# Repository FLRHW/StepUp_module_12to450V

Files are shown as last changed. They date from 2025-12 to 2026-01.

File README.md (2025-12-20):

<p align="center" width="100%">
  <a href="https://github.com/FLRHW/StepUp_module_12to450V/actions/workflows/ci.yaml">
    
  </a>
</p>

<p align="center" width="100%">
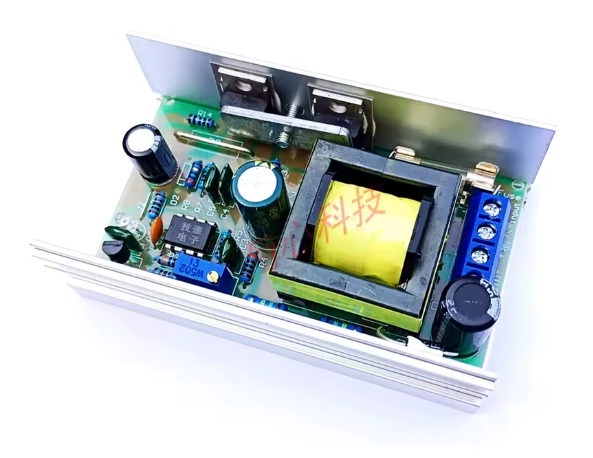
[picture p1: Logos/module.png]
    
</p>

***

<p align="center">
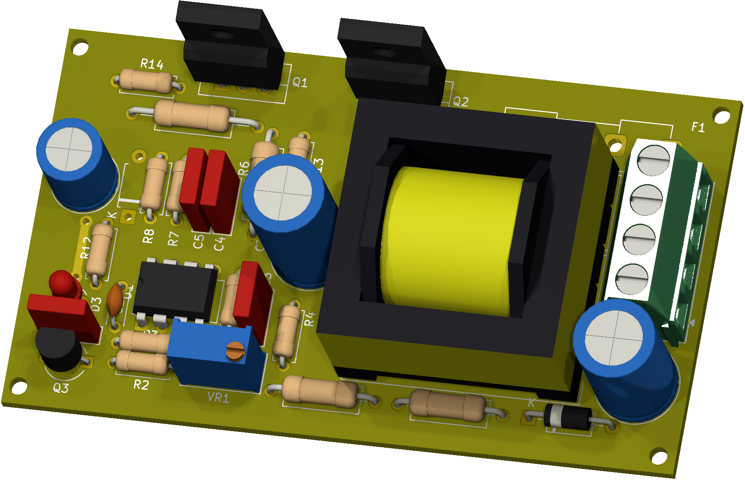
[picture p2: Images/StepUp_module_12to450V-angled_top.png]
3D Top Angled
  
&nbsp; &nbsp; &nbsp; &nbsp;
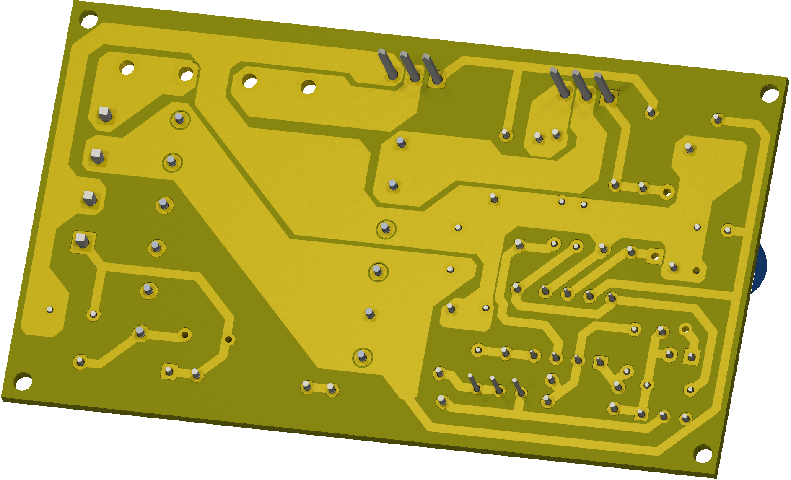
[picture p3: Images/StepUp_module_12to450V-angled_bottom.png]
3D Bottom Angled
  
</p>

***

# **StepUp_module_12to450V**
This repository contains a reverse‑engineered KiCad schematic and PCB layout from a commercial module originally purchased from AliExpress.

## Project overview
This project documents the electrical design and PCB layout of a third‑party module by recreating them from scratch in KiCad for learning, repair, and interoperability purposes. The repository does not include any original vendor design files, firmware, branding, or trademarks.

## Origin and scope
Original hardware: generic module purchased from AliExpress (exact vendor and listing may change over time, the following terms can help finding similar modules: "70W DC-DC 12V 24V To 200V-450V Voltage Adjustable Boost Power Converter Nixie Clock Tube Amplifier Capacitor Charging").  
Status: unofficial, reverse‑engineered reference design; not affiliated with, endorsed by, or supported by the original manufacturer or seller.  
Contents: KiCad schematic, PCB layout, netlists, and supporting documentation created from measurements and inspection of a physical unit.

## Intended use
This repository is intended for:
* Educational use and study of the circuit;
* Repair, modification, or replacement of compatible hardware;
* Integration into hobby or research projects, subject to any third‑party IP that may apply in your jurisdiction. Users are responsible for checking any patent, copyright, or regulatory constraints that may apply to their own use.

## License
The KiCad design files and documentation in this repository are released under the CERN Open Hardware Licence v2 – Permissive (CERN‑OHL‑P‑2.0). SPDX identifier: CERN-OHL-P-2.0 See the LICENSE file for the full legal text and conditions.  
In short and non‑legal terms, you are free to use, modify, manufacture, and distribute hardware based on these files, provided you respect attribution requirements and the terms in the license.

## Trademarks and third‑party rights
All product names, logos, and brands of the original module are the property of their respective owners and are not included or licensed here.  
Any reference to third‑party marks is purely descriptive and does not imply endorsement or affiliation.  
If you are the rights holder for the original hardware and have concerns about this documentation, please open an issue in the repository.

## Safety and disclaimer
* The design is provided as is, with no warranty of any kind;
* Use it at your own risk; always review the schematic, layout, and component ratings before using it;
* High voltage can cause injury, death, or damage to equipment; ensure appropriate protections and testing procedures.

## Contributing
Contributions are welcome. Please use pull requests and issues to propose changes or discuss potential improvements.

***

## DIRECTORY STRUCTURE
    │
    ├─ Computations       # Misc calculations
    ├─ HTML               # HTML files for generated webpage
    ├─ Images             # Pictures and renders
    │
    ├─ kibot_resources    # External resources for KiBot
    │  ├─ colors          # Color theme for KiCad
    │  ├─ fonts           # Fonts used in the project
    │  ├─ scripts         # External scripts used with KiBot
    │  └─ templates       # Templates for KiBot generated reports
    │
    ├─ kibot_yaml         # KiBot YAML config files
    ├─ KiRI               # KiRI (PCB diff viewer) files
    │
    ├─ lib                # KiCad footprint and symbol libraries
    │  ├─ 3d_models       # Component 3D models
    │  ├─ lib_fp          # Footprint libraries
    │  └─ lib_sym         # Symbol libraries
    │
    ├─ Logos              # Logos
    │
    ├─ Manufacturing      # Assembly and fabrication documents
    │  ├─ Assembly        # Assembly documents (BoM, pos, notes)
    │  │
    │  └─ Fabrication     # Fabrication documents (ZIP, notes)
    │     ├─ Drill Tables # CSV drill tables
    │     └─ Gerbers      # Gerbers
    │
    ├─ Report             # Reports for ERC/DRC
    ├─ Schematic          # PDF of schematic
    ├─ Templates          # Title block templates
    ├─ Testing
    │  └─ Testpoints      # Testpoints tables      
    │
    └─ Variants           # Outputs for assembly variants

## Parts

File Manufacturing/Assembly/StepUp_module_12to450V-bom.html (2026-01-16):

 | Bill of Materials
 | Schematic: StepUp_module_12to450V Variant: RELEASED Revision: 1.1.0 Date: 2025-12-20 KiCad Version: 9.0.6+1 | Component Groups: 22 Component Count: 31 (per PCB) Fitted Components: 31 (per PCB) Number of PCBs: 1 Total Components: 31 (for 1 PCBs)
Row | Quantity Per PCB | References | Value | Datasheet | Footprint | Description | Manufacturer | Manufacturer Part Number | Supplier Part Number
1 | 3 | C1 C4 C5 | 10n | ~ | C_Rect_L7.0mm_W2.0mm_P5.00mm | Unpolarized capacitor
2 | 1 | C3 | 3,3n | ~ | C_Rect_L7.0mm_W2.0mm_P5.00mm | Unpolarized capacitor
3 | 1 | C2 | 100n | ~ | C_Disc_D4.3mm_W1.9mm_P5.00mm | Unpolarized capacitor
4 | 1 | C8 | 10u | ~ | C_Radial_D10.0mm_H16.0mm_P5.00mm | Polarized capacitor
5 | 1 | C6 | 100u | ~ | C_Radial_D8.0mm_H11.5mm_P3.50mm | Polarized capacitor
6 | 1 | C7 | 1000u | ~ | C_Radial_D10.0mm_H20.0mm_P5.00mm | Polarized capacitor
7 | 3 | D4 F1 TR1 | ? | ~ | D_A-405_P10.16mm_Horizontal | Diode Fuse
8 | 1 | D3 | LED | ~ | LED_D3.0mm | Light emitting diode
9 | 1 | J1 | Screw_Terminal_01x04 | ~ | TerminalBlock_Phoenix_MKDS-1,5-4_1x04_P5.00mm_Horizontal | Generic screw terminal, single row, 01x04, script generated (kicad-library-utils/schlib/autogen/connector/)
10 | 2 | Q1 Q2 | HY1707 | ~ | TO-220F-3_Vertical | N-MOSFET transistor, gate/drain/source
11 | 1 | Q3 | S8050 | http://www.unisonic.com.tw/datasheet/S8050.pdf | TO-92_Inline_Wide | 0.7A Ic, 20V Vce, Low Voltage High Current NPN Transistor, TO-92
12 | 1 | R9 | 13.7m | ~ | R_Axial_DIN0309_L9.0mm_D3.2mm_P15.24mm_Horizontal | Resistor
13 | 1 | R8 | 20 | ~ | R_Axial_DIN0207_L6.3mm_D2.5mm_P7.62mm_Horizontal | Resistor
14 | 1 | R14 | 100 | ~ | R_Axial_DIN0207_L6.3mm_D2.5mm_P7.62mm_Horizontal | Resistor
15 | 1 | R6 | 150 | ~ | R_Axial_DIN0309_L9.0mm_D3.2mm_P12.70mm_Horizontal | Resistor
16 | 2 | R2 R12 | 1k | ~ | R_Axial_DIN0207_L6.3mm_D2.5mm_P7.62mm_Horizontal | Resistor
17 | 1 | R4 | 3k | ~ | R_Axial_DIN0207_L6.3mm_D2.5mm_P7.62mm_Horizontal | Resistor
18 | 3 | R5 R7 R13 | 5,1k | ~ | R_Axial_DIN0207_L6.3mm_D2.5mm_P7.62mm_Horizontal | Resistor
19 | 1 | R3 | 100k | ~ | R_Axial_DIN0207_L6.3mm_D2.5mm_P7.62mm_Horizontal | Resistor
20 | 2 | R10 R11 | 140k | ~ | R_Axial_DIN0309_L9.0mm_D3.2mm_P12.70mm_Horizontal | Resistor
21 | 1 | U1 | UC3845 |  | DIP-8_W7.62mm
22 | 1 | VR1 | 5k | ~ | Potentiometer_Bourns_3296W_Vertical | Trim-potentiometer
Color reference for columns:
KiCad Fields (default)
Generated Fields
User Fields
Empty Fields

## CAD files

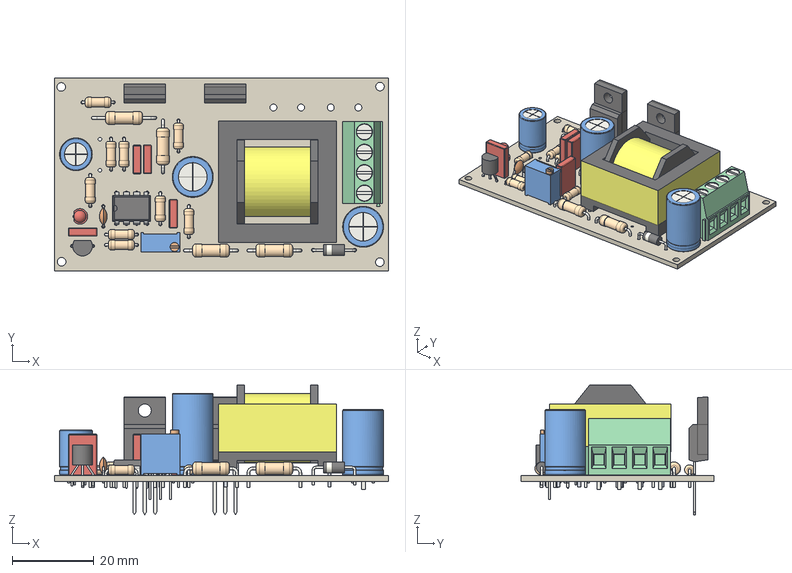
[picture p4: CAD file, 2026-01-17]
3D/StepUp_module_12to450V.step
81.8 x 47.2 x 31.8 mm
C_Rect_L7.0mm_W2.0mm_P5.00mm x 4
R_Axial_DIN0309_L9.0mm_D3.2mm_P12.70mm_Horizontal x 3
LED_D3.0mm
TerminalBlock_Phoenix_MKDS-1,5-4_1x04_P5.00mm_Horizontal
R_Axial_DIN0207_L6.3mm_D2.5mm_P7.62mm_Horizontal x 9
DIP-8_W7.62mm
C_Radial_D10.0mm_H16.0mm_P5.00mm
Trafo_12to450V_module
TO-220F-3_Vertical x 2
R_Axial_DIN0309_L9.0mm_D3.2mm_P15.24mm_Horizontal
C_Disc_D4.3mm_W1.9mm_P5.00mm
TO-92_Inline_Wide
C_Radial_D8.0mm_H11.5mm_P3.50mm
Potentiometer_Bourns_3296W_Vertical
D_A-405_P10.16mm_Horizontal
C_Radial_D10.0mm_H20.0mm_P5.00mm
kibot_6br3e5ev_PCB

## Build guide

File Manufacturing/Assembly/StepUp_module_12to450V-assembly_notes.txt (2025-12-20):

ASSEMBLY NOTES (UNLESS OTHERWISE SPECIFIED)

1)	DO NOT POPULATE PARTS MARKED WITH A RED CROSS.

2)	IF CONFLICTING INFORMATION IS FOUND BETWEEN THE ASSEMBLY
	FILE AND BOM, BOM SHOULD BE USED AS THE MAIN SOURCE.

3)	DOT IDENTIFIES PIN #1 LOCATION AND DEVICE ORIENTATION
	WHEN VIEWED FROM THE TOP.

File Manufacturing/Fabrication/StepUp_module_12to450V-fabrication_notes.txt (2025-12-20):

FABRICATION NOTES (UNLESS OTHERWISE SPECIFIED)

1)	FABRICATE PER IPC-6012A CLASS 2.

2)	OUTLINE DEFINED IN SEPARATE GERBER FILE WITH
	"Edge_Cuts.GBR" SUFFIX.

	DIMENSIONS OF CIRCUMSIZED RECTANGLE SHOWN ON THIS
	DRAWING ARE FOR REFERENCE ONLY.

3)	SEE SEPARATE DRILL FILES WITH ".DRL" SUFFIX 
	FOR HOLE LOCATIONS.

	SELECTED HOLE LOCATIONS SHOWN ON THIS DRAWING 
	ARE FOR REFERENCE ONLY.

4)	SURFACE FINISH: IMMERSION GOLD

5)	SOLDERMASK ON BOTH SIDES OF THE BOARD SHALL 
	BE LPI, COLOR TOP: #8071501A / BOTTOM: GREEN.

6)	SILK SCREEN LEGEND TO BE APPLIED PER LAYER 
	STACKUP USING WHITE NON-CONDUCTIVE EPOXY INK.

7)	ALL VIAS ARE TENTED ON BOTH SIDES UNLESS 
	SOLDERMASK OPENED IN GERBER.

8)	VENDOR SHOULD FOLLOW ROHS COMPLIANT PROCESS 
	AND Pb FREE FOR MANUFACTURING

9)	PCB MATERIAL REQUIREMENTS:

	A.	FLAMMABILITY RATING MUST MEET OR EXCEED 
		UL94V-0 REQUIREMENTS.
	B.	Tg 170 C OR EQUIVALENT.
	C.	EQUIVALENT MATERIAL SHALL BE RoHS COMPLIANT, 
		HALOGEN FREE AND APPROVED BY FR.

10)	DESIGN GEOMETRY MINIMUM FEATURE SIZES:

	BOARD SIZE				81.800 × 47.200 mm
	BOARD THICKNESS		1.660 mm
	TRACE WIDTH			1.000 mm
	TRACE TO TRACE		0.200 mm
	MIN. HOLE (PTH)			0.800 mm
	MIN. HOLE (NPTH)		2.100 mm
	ANNULAR RING			0.320 mm
	COPPER TO HOLE		0.254 mm
	COPPER TO EDGE		0.250 mm
	HOLE TO HOLE			0.254 mm

11)	REFER TO IMPEDANCE TABLE FOR IMPEDANCE CONTROL REQUIREMENTS.

12)	CONFIRM SPACE WIDTHS AND SPACINGS.

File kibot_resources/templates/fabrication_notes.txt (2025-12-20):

FABRICATION NOTES (UNLESS OTHERWISE SPECIFIED)

1)	FABRICATE PER IPC-6012A CLASS 2.

2)	OUTLINE DEFINED IN SEPARATE GERBER FILE WITH
	"Edge_Cuts.GBR" SUFFIX.

	DIMENSIONS OF CIRCUMSIZED RECTANGLE SHOWN ON THIS
	DRAWING ARE FOR REFERENCE ONLY.

3)	SEE SEPARATE DRILL FILES WITH ".DRL" SUFFIX 
	FOR HOLE LOCATIONS.

	SELECTED HOLE LOCATIONS SHOWN ON THIS DRAWING 
	ARE FOR REFERENCE ONLY.

4)	SURFACE FINISH: ${pcb_finish_cap}

5)	SOLDERMASK ON BOTH SIDES OF THE BOARD SHALL 
	BE LPI, COLOR ${solder_mask_color_text_cap}.

6)	SILK SCREEN LEGEND TO BE APPLIED PER LAYER 
	STACKUP USING ${silk_screen_color_text_cap} NON-CONDUCTIVE EPOXY INK.

7)	ALL VIAS ARE TENTED ON BOTH SIDES UNLESS 
	SOLDERMASK OPENED IN GERBER.

8)	VENDOR SHOULD FOLLOW ROHS COMPLIANT PROCESS 
	AND Pb FREE FOR MANUFACTURING

9)	PCB MATERIAL REQUIREMENTS:

	A.	FLAMMABILITY RATING MUST MEET OR EXCEED 
		UL94V-0 REQUIREMENTS.
	B.	Tg 170 C OR EQUIVALENT.
	C.	EQUIVALENT MATERIAL SHALL BE RoHS COMPLIANT, 
		HALOGEN FREE AND APPROVED BY ${COMPANY_cap}.

10)	DESIGN GEOMETRY MINIMUM FEATURE SIZES:

	BOARD SIZE				${bb_w_mm} × ${bb_h_mm} mm
	BOARD THICKNESS		${thickness_mm} mm
	TRACE WIDTH			${track_mm} mm
	TRACE TO TRACE		${clearance_mm} mm
	MIN. HOLE (PTH)			${drill_pth_real_mm} mm
	MIN. HOLE (NPTH)		${drill_npth_real_mm} mm
	ANNULAR RING			${oar_mm} mm
	COPPER TO HOLE		${c2h_mm} mm
	COPPER TO EDGE		${c2e_mm} mm
	HOLE TO HOLE			${h2h_mm} mm
#?stackup and impedance_controlled

#?stackup and impedance_controlled
11)	REFER TO IMPEDANCE TABLE FOR IMPEDANCE CONTROL REQUIREMENTS.
#?stackup and impedance_controlled

#?stackup and impedance_controlled
12)	CONFIRM SPACE WIDTHS AND SPACINGS.

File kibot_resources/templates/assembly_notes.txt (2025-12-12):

ASSEMBLY NOTES (UNLESS OTHERWISE SPECIFIED)

1)	DO NOT POPULATE PARTS ARE MARKED WITH A RED CROSS.

2)	DO NOT POPULATE PARTS ARE NOT PRESENT IN THE BOM.

3)	IF CONFLICTING INFORMATION IS FOUND BETWEEN THE ASSEMBLY
	FILE AND BOM, BOM SHOULD BE USED AS THE MAIN SOURCE.

4)	CONFORMAL COATING IS NOT REQUIRED.

5)	DOT IDENTIFIES PIN #1 LOCATION AND DEVICE ORIENTATION
	WHEN VIEWED FROM THE TOP.

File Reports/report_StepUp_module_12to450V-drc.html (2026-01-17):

Logo

| DRC report for StepUp_module_12to450V
| PCB: StepUp_module_12to450V Revision: 1.1.0 Date: 2026-01-17T14:19:15+0000 KiCad Version: 9.0.6 | Errors: 0 Warnings: 0 Total: 0

✔

Generated by KiBot (https://github.com/INTI-CMNB/KiBot/) v1.8.6

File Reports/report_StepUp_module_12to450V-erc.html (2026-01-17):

Logo

| ERC report for StepUp_module_12to450V
| Schematic: StepUp_module_12to450V Revision: 1.1.0 Date: 2026-01-17T14:19:13+0000 KiCad Version: 9.0.6 | Errors: 0 Warnings: 3 Total: 3

Sheet / (StepUp_module_12to450V.kicad_sch)

Type | Description | Details
lib_symbol_issues | The current configuration does not include the symbol library 'personal' | @(1.8288 mm, 0.8636 mm): Symbol U1 [UC3845]
footprint_link_issues | The current configuration does not include the footprint library 'Personal'. | @(2.3876 mm, 0.5842 mm): Symbol TR1 [TR_12to450V_alixp]
lib_symbol_issues | The current configuration does not include the symbol library 'personal' | @(2.3876 mm, 0.5842 mm): Symbol TR1 [TR_12to450V_alixp]

Generated by KiBot (https://github.com/INTI-CMNB/KiBot/) v1.8.6

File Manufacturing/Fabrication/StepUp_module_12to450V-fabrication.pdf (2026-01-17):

# Top Fabrication (Scale 1:1)

# Module Fabrication Document

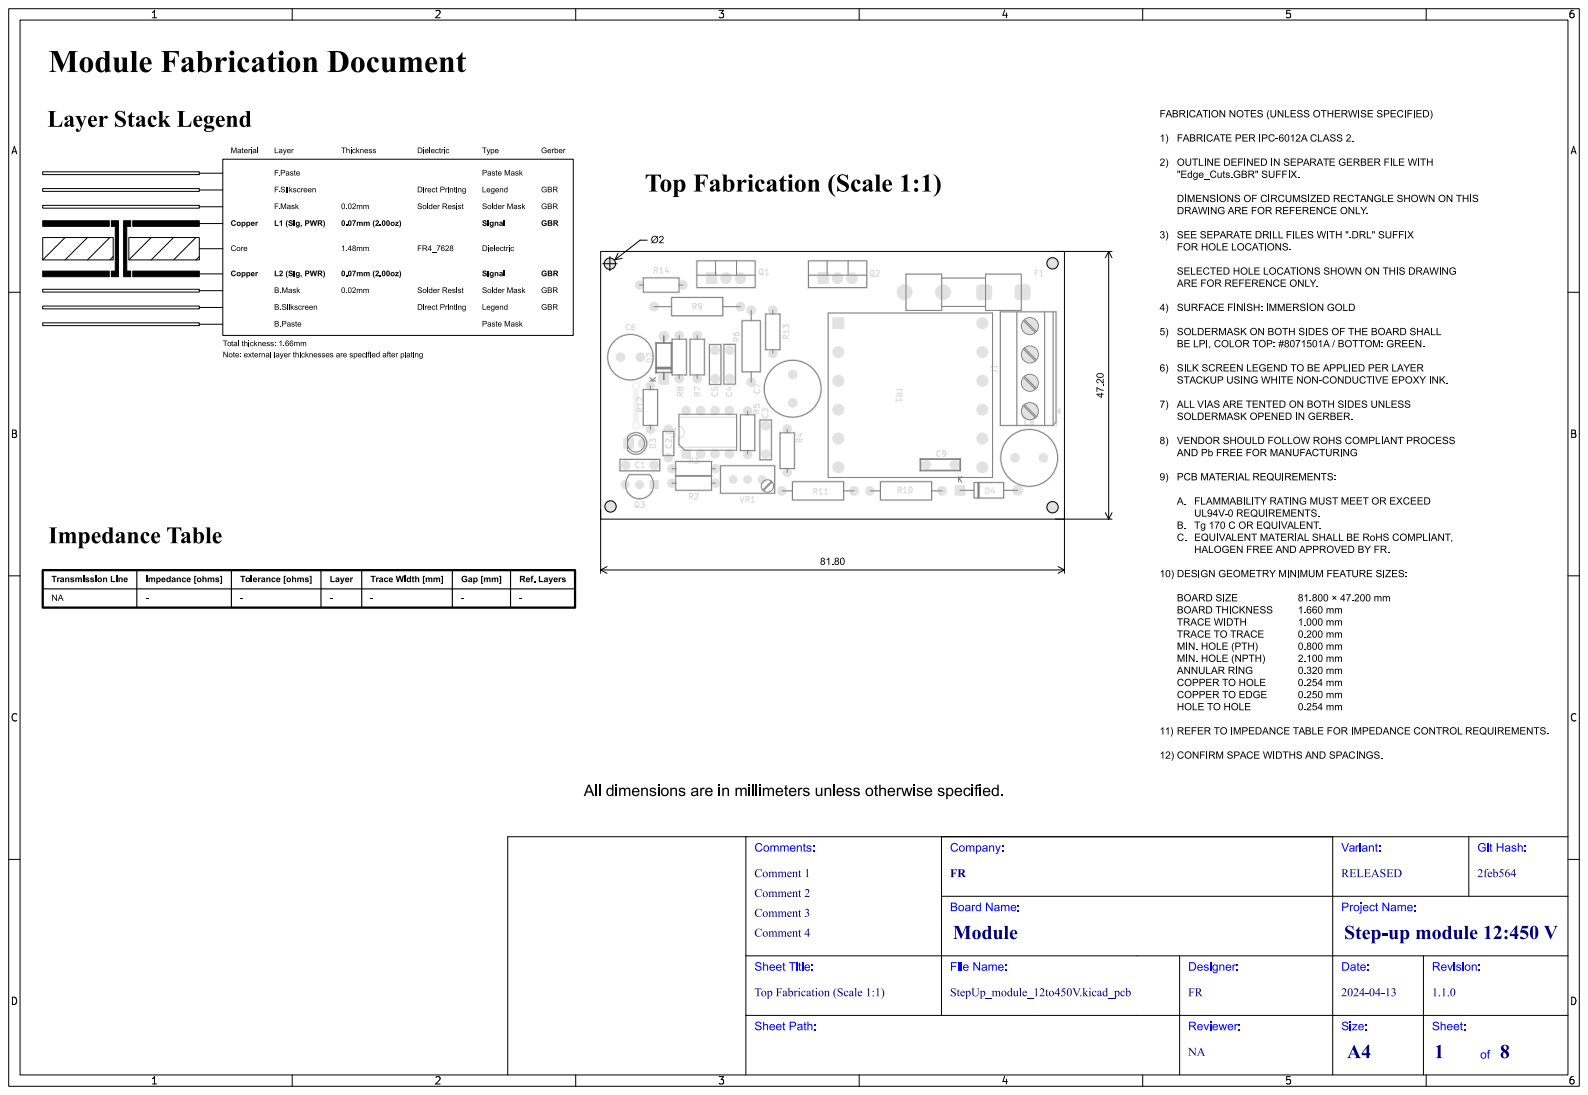
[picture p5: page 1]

# Bottom Fabrication (Scale 1:1)

# Module Fabrication Document

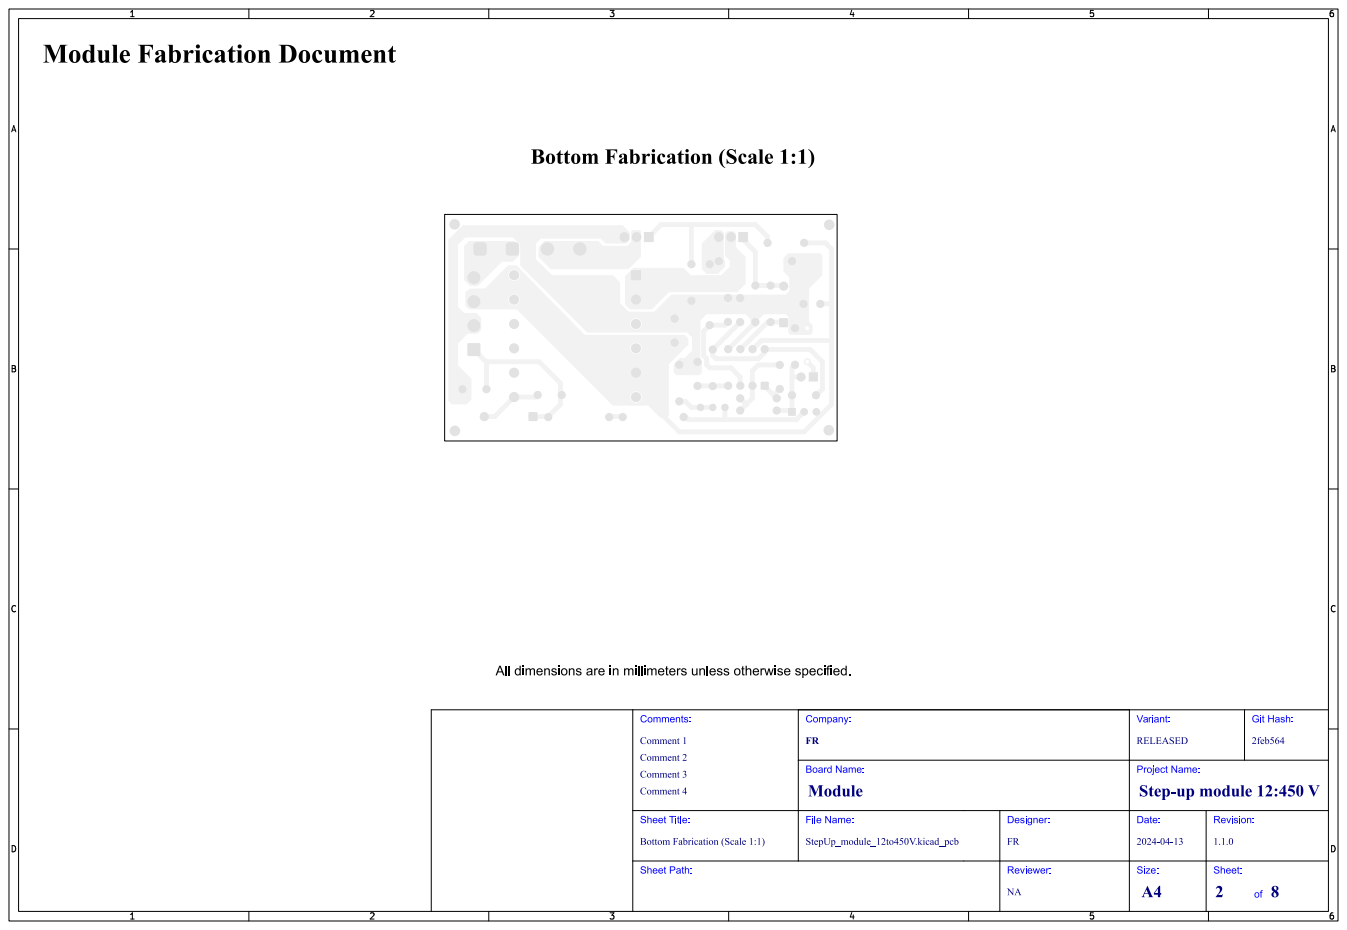
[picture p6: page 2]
Git; Hash:; 2feb564; Comment 4; Comment 3; Comment 2; Comment 1; Comments:; Sheet Path:; Sheet Title:; File Name:; Module; Step-up module 12:450 V; Company:; RELEASED; Variant:; Board Name:; StepUp_module_12to450V.kicad_pcb; Designer:; Reviewer:; Project Name:; Date:; Revision:; Size:; Sheet:

Bottom Fabrication (Scale 1:1)

# Drill Drawing L1 - L2 (Scale 1:1)

# Module Fabrication Document

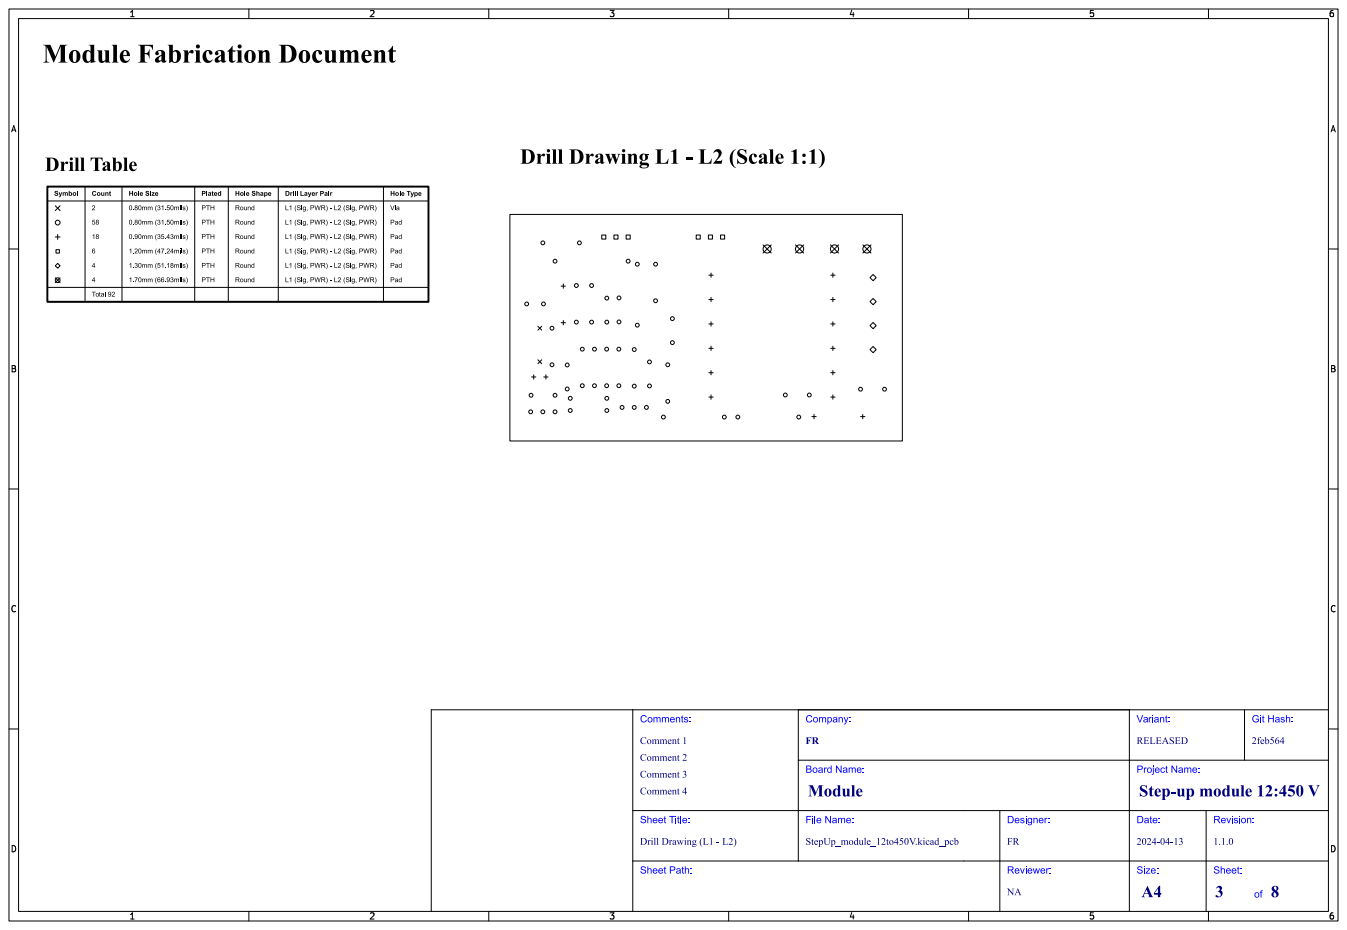
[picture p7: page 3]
Git; Hash:; 2feb564; Comment 4; Comment 3; Comment 2; Comment 1; Comments:; Drill Drawing (L1 - L2); Sheet Path:; Sheet Title:; File Name:; Module; Step-up module 12:450 V; Company:; RELEASED; Variant:; Board Name:; StepUp_module_12to450V.kicad_pcb; Designer:; Reviewer:; Project Name:; Date:; Revision:; Size:; Sheet:

# Drill Drawing L1 - L2 (Scale 1:1)

# Module Fabrication Document

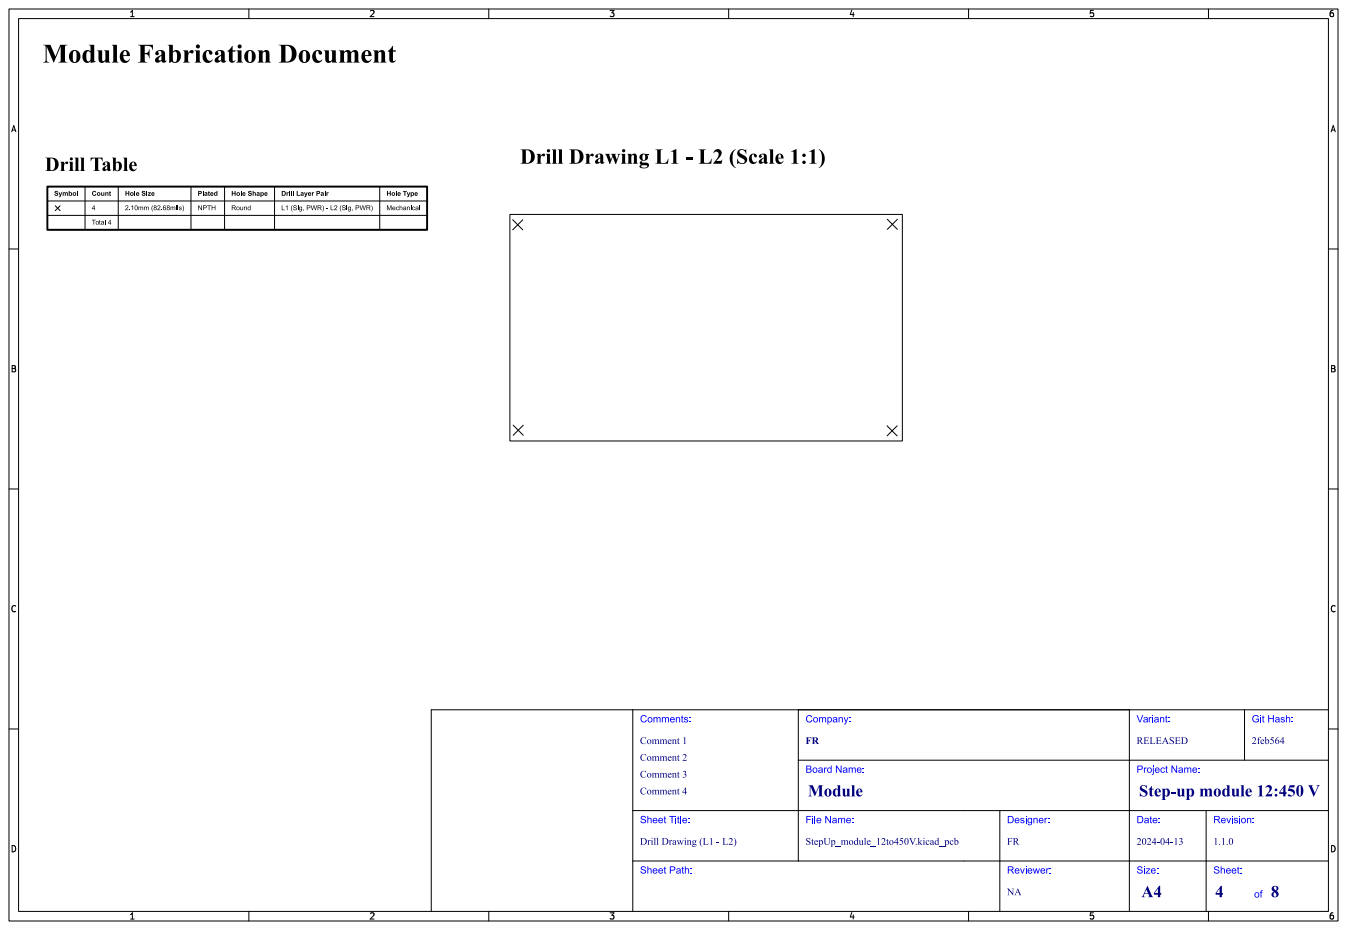
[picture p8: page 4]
Git; Hash:; 2feb564; Comment 4; Comment 3; Comment 2; Comment 1; Comments:; Drill Drawing (L1 - L2); Sheet Path:; Sheet Title:; File Name:; Module; Step-up module 12:450 V; Company:; RELEASED; Variant:; Board Name:; StepUp_module_12to450V.kicad_pcb; Designer:; Reviewer:; Project Name:; Date:; Revision:; Size:; Sheet:

# Top Test Points (Scale 1:1)

# Module Fabrication Document

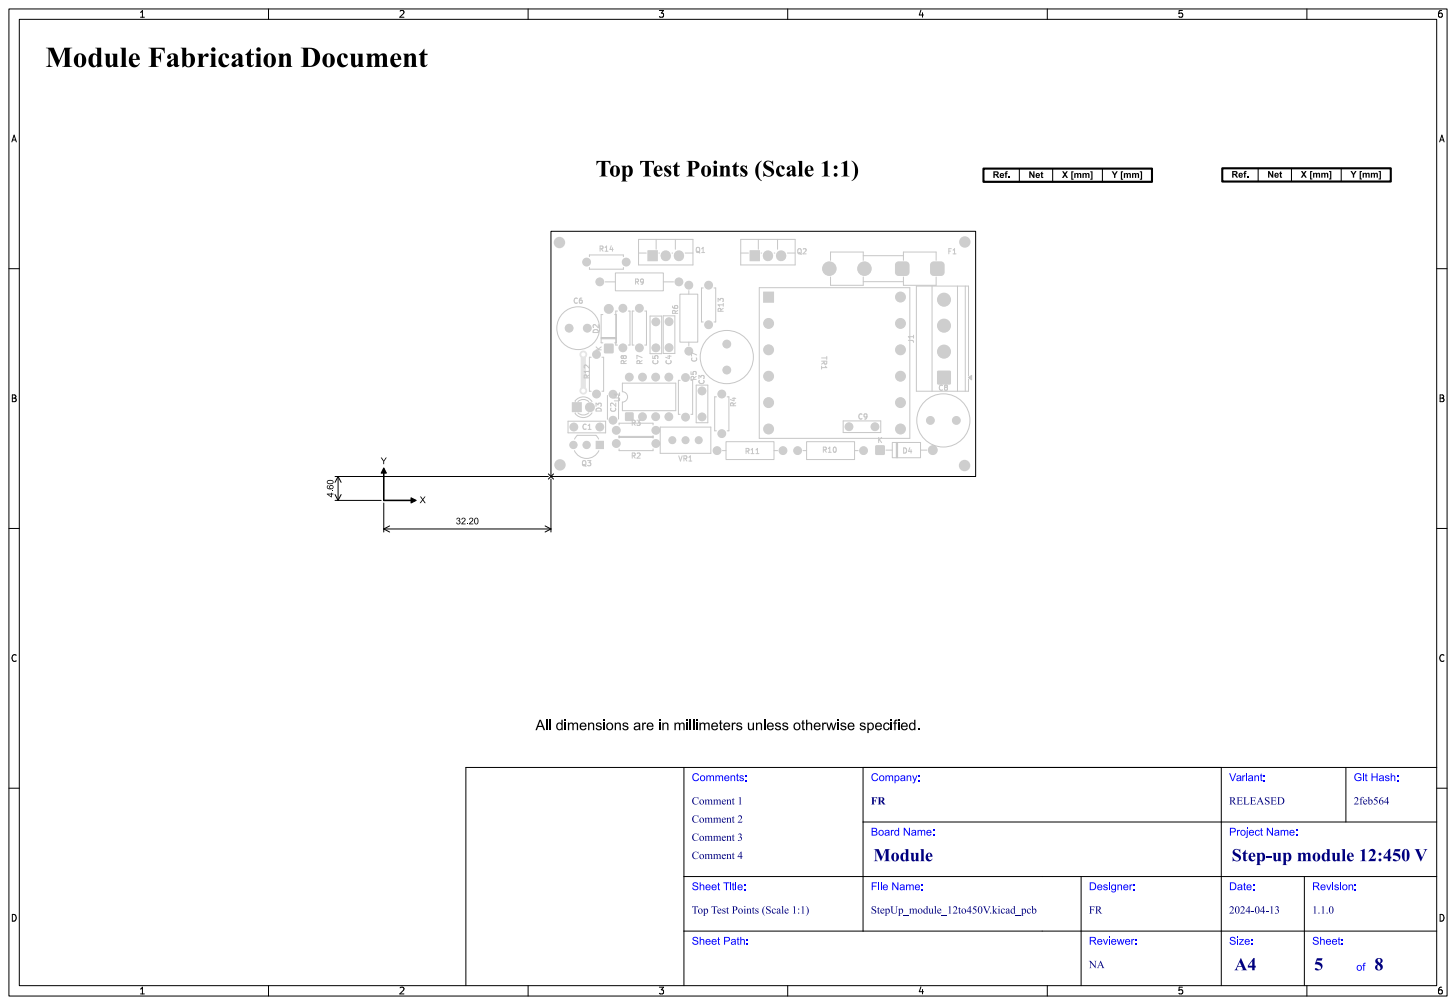
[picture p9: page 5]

Top Test Points (Scale 1:1)

# Bottom Test Points (Scale 1:1)

# Module Fabrication Document

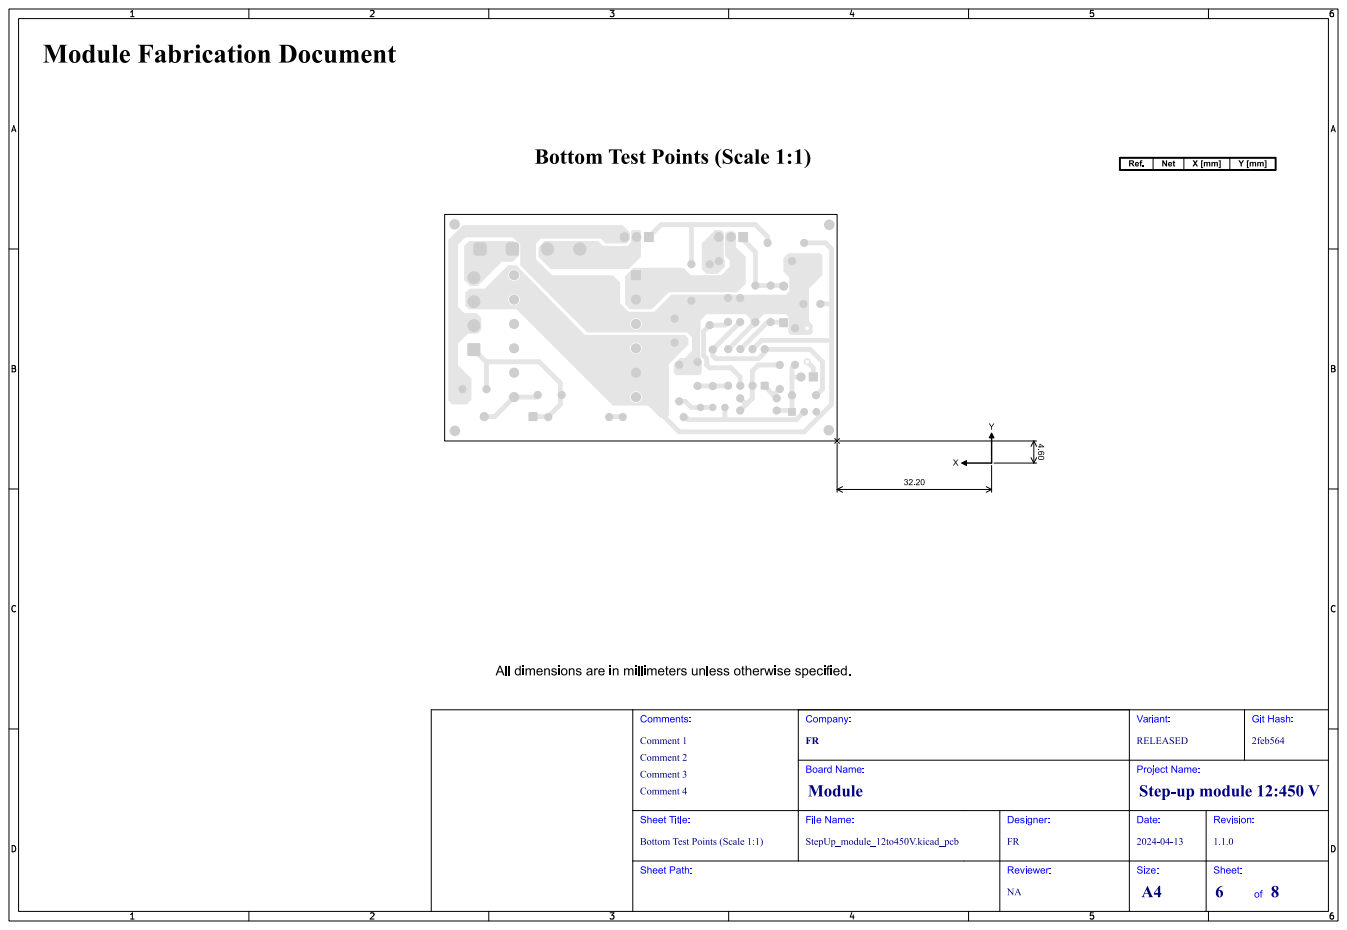
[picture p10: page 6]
Git; Hash:; 2feb564; Comment 4; Comment 3; Comment 2; Comment 1; Comments:; Sheet Path:; Sheet Title:; File Name:; Module; Step-up module 12:450 V; Company:; RELEASED; Variant:; Board Name:; StepUp_module_12to450V.kicad_pcb; Designer:; Reviewer:; Project Name:; Date:; Revision:; Size:; Sheet:

Bottom Test Points (Scale 1:1)

# L1 (Sig, PWR) (Scale 1:1)

# Module Fabrication Document

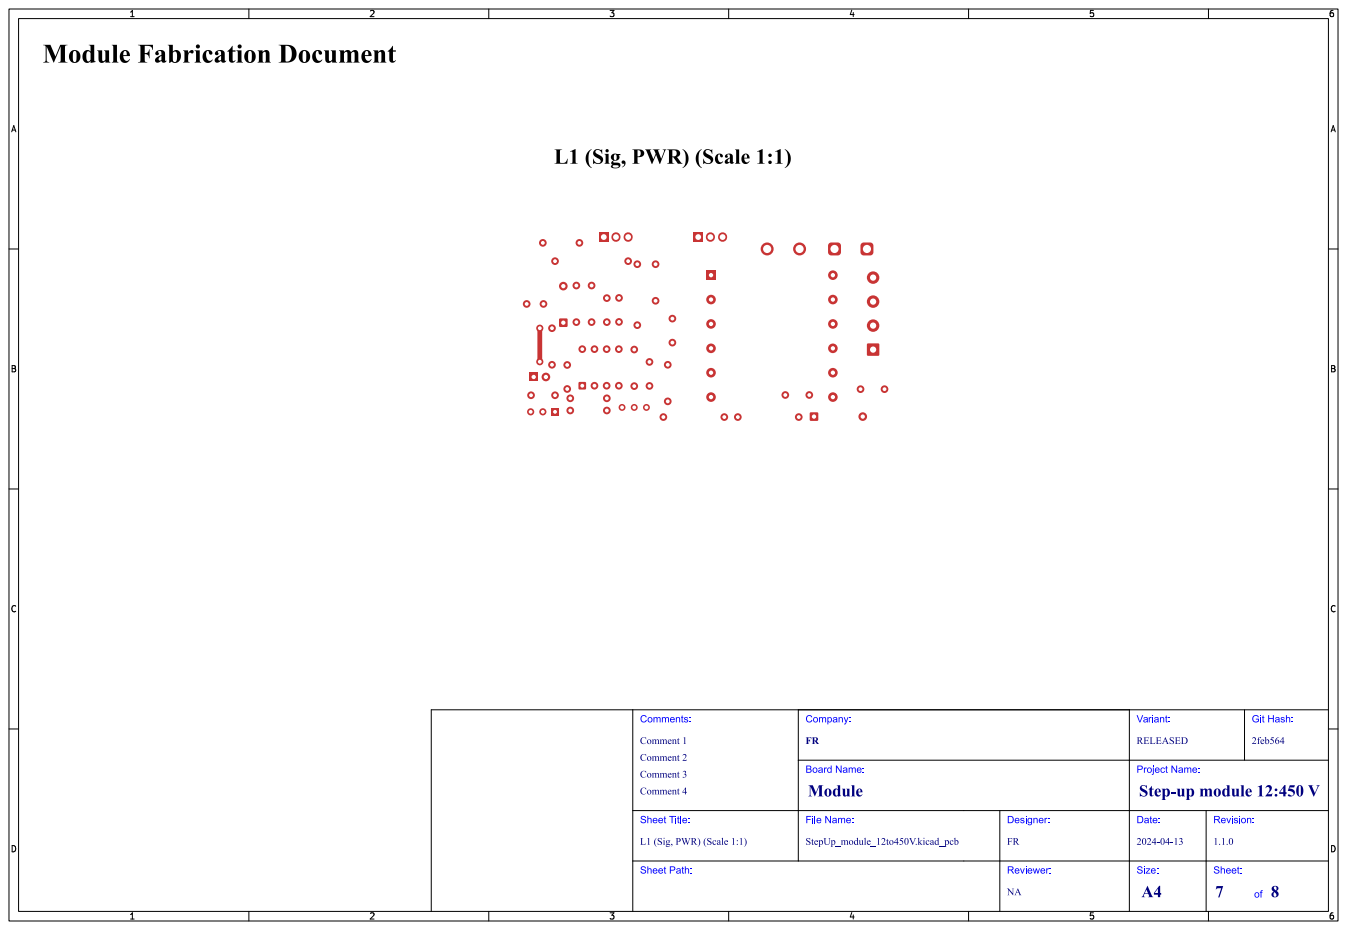
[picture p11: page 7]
Git; Hash:; 2feb564; Comment 4; Comment 3; Comment 2; Comment 1; Comments:; Sheet Path:; Sheet Title:; File Name:; Module; Step-up module 12:450 V; Company:; RELEASED; Variant:; Board Name:; StepUp_module_12to450V.kicad_pcb; Designer:; Reviewer:; Project Name:; Date:; Revision:; Size:; Sheet:

L1 (Sig, PWR) (Scale 1:1)

# L2 (Sig, PWR) (Scale 1:1)

# Module Fabrication Document

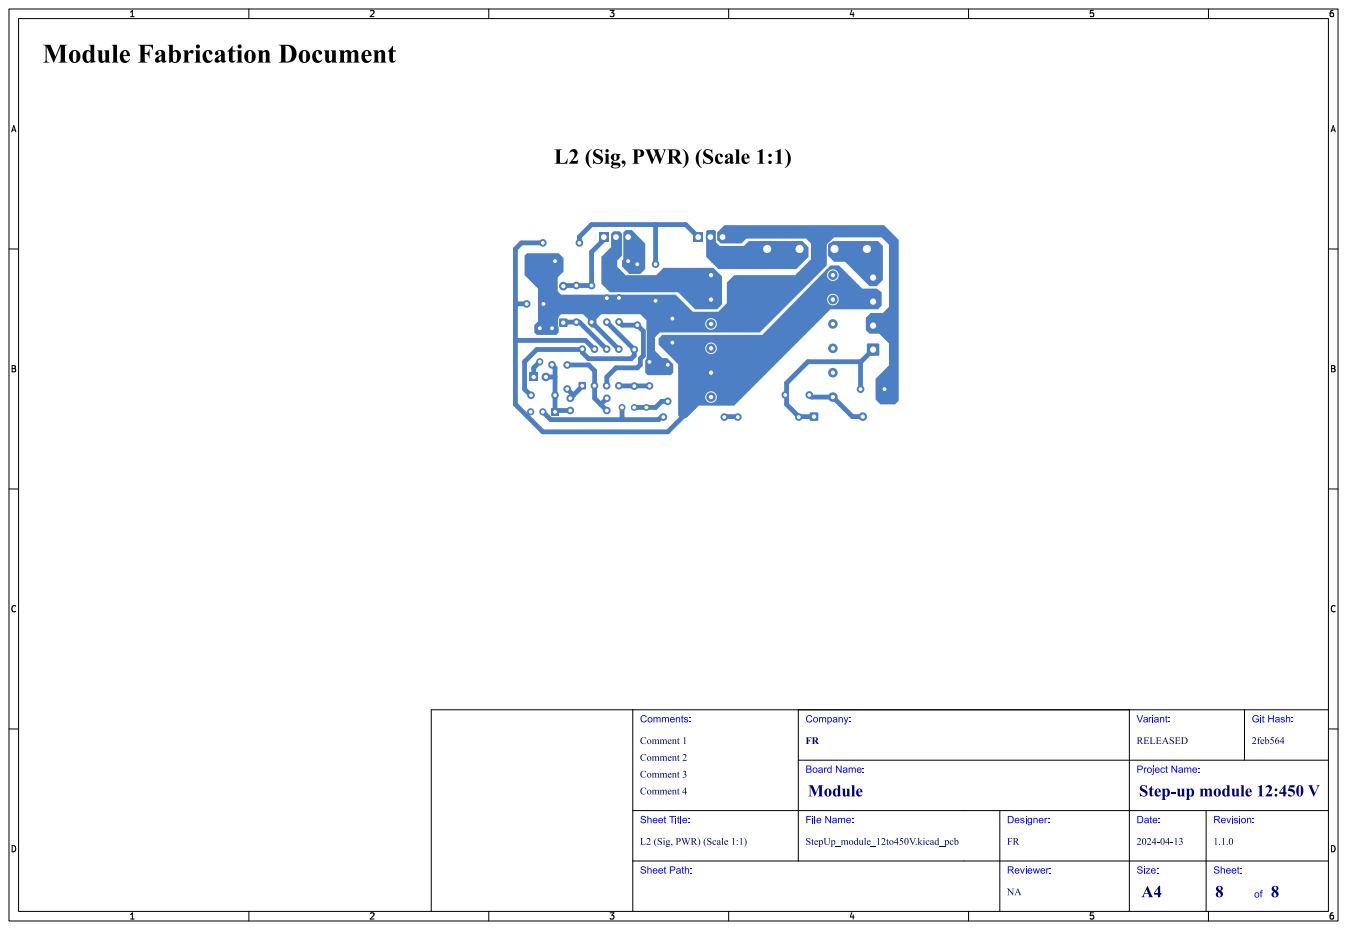
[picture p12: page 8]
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

L2 (Sig, PWR) (Scale 1:1)

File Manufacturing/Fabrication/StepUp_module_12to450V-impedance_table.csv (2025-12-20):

Transmission Line | Impedance [ohms] | Tolerance [ohms] | Layer | Trace Width [mm] | Gap [mm] | Ref. Layers
NA | - | - | - | - | - | -

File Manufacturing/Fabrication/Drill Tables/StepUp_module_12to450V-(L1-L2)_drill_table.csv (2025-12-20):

Count | Hole Size | Plated | Hole Shape | Drill Layer Pair | Hole Type
2 | 0.80mm (31.50mils) | PTH | Round | L1 (Sig, PWR) - L2 (Sig, PWR) | Via
58 | 0.80mm (31.50mils) | PTH | Round | L1 (Sig, PWR) - L2 (Sig, PWR) | Pad
18 | 0.90mm (35.43mils) | PTH | Round | L1 (Sig, PWR) - L2 (Sig, PWR) | Pad
6 | 1.20mm (47.24mils) | PTH | Round | L1 (Sig, PWR) - L2 (Sig, PWR) | Pad
4 | 1.30mm (51.18mils) | PTH | Round | L1 (Sig, PWR) - L2 (Sig, PWR) | Pad
4 | 1.70mm (66.93mils) | PTH | Round | L1 (Sig, PWR) - L2 (Sig, PWR) | Pad
Total 92

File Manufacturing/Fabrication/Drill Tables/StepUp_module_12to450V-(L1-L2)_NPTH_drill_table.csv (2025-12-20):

Count | Hole Size | Plated | Hole Shape | Drill Layer Pair | Hole Type
4 | 2.10mm (82.68mils) | NPTH | Round | L1 (Sig, PWR) - L2 (Sig, PWR) | Mechanical
Total 4

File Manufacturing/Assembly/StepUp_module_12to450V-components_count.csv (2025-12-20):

Type | Front Side | Back Side | Total
THT | 31 | 0 | 31
SMD | 0 | 0 | 0
Total | 31 | 0 | 31

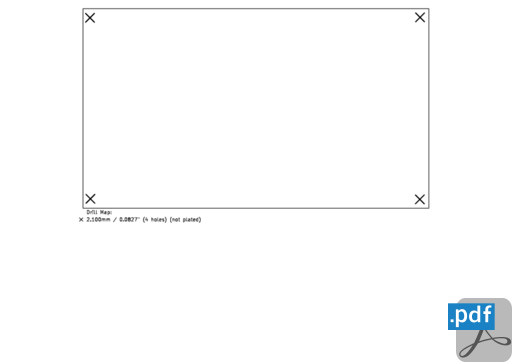
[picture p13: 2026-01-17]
HTML/images/cat_pdf_drill_map_StepUp_module_12to450V-NPTH_drill_map.png

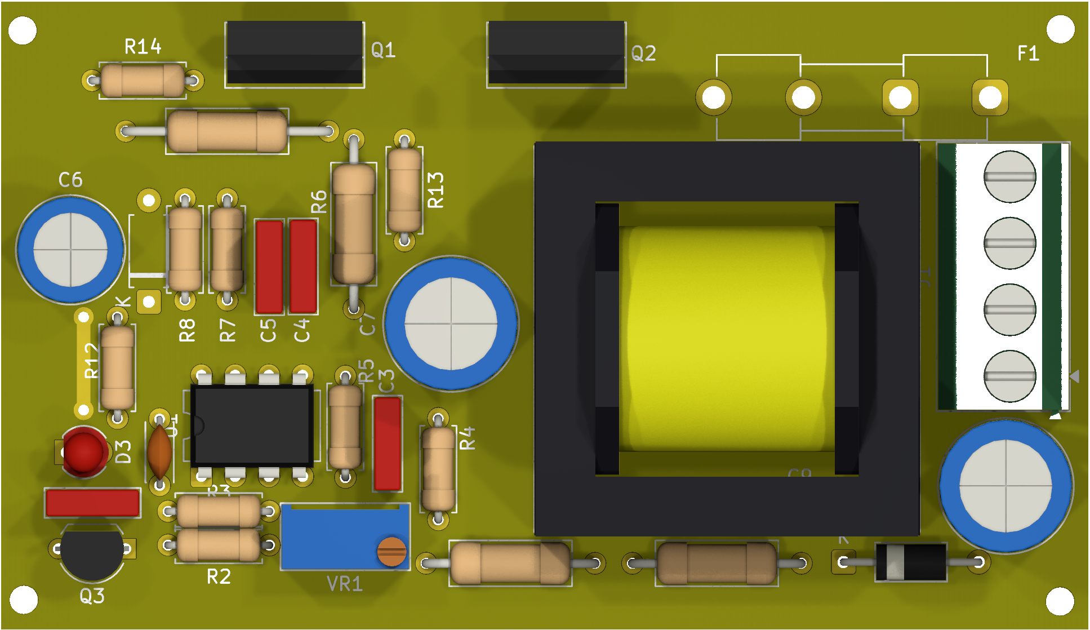
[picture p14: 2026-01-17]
Images/StepUp_module_12to450V-top.png

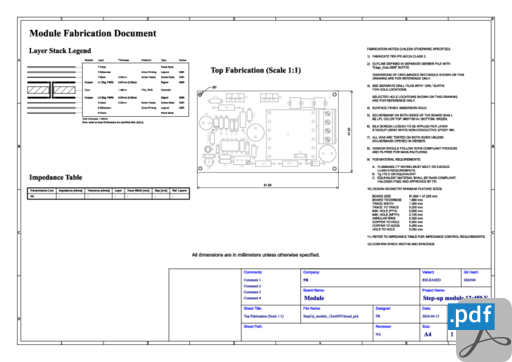
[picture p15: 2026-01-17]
HTML/images/cat_pdf_fabrication_StepUp_module_12to450V-fabrication.png

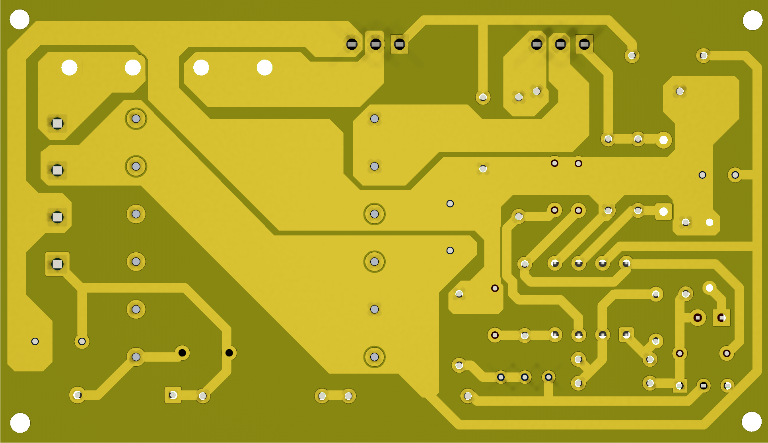
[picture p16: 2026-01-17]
Images/StepUp_module_12to450V-bottom.png

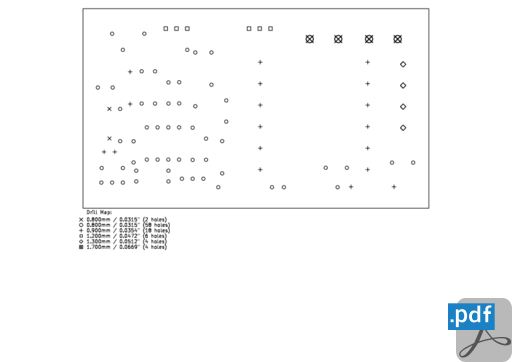
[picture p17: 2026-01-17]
HTML/images/cat_pdf_drill_map_StepUp_module_12to450V-PTH_drill_map.png

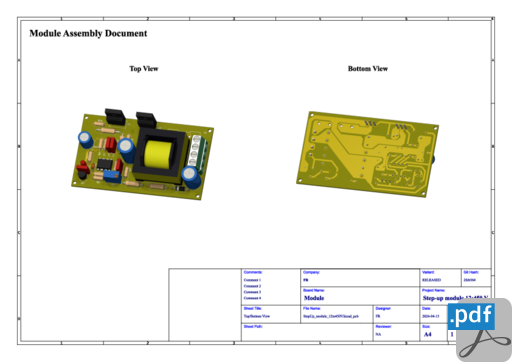
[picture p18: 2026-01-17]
HTML/images/cat_pdf_assembly_StepUp_module_12to450V-assembly.png

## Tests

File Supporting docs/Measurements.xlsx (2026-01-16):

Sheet: Waveforms
Ch | Node
1 | D4 anode
2 | U1 pin 4
3 | Q1 drain
4 | Q1 source
Load [kΩ] | 11.66 | 0.87
Vin [V] | 12 | 12
Vout [V] | 245 | 230
Iin[A] | 0.55 | 7.11

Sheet: Transformer
Winding | Primary | Primary | Secondary
Applied current [A] | 1.02 | 2.527 | 1.02
Measured drop [mV] | 7.6 | 18.9 | 475
Calculated resistance [mΩ] | 7.45 | 7.48 | 465.69
Frequency [kHz] | 49.92 | 59.78 | 69.91 | 80.00 | 89.82 | 100.00 | 110.02 | 119.93 | 130.21 | 140.10 | 149.97 | 160.31 | 169.87 | 179.79 | 189.90 | 199.96
Primary [V] | 0.05 | 0.07 | 0.08 | 0.09 | 0.10 | 0.11 | 0.12 | 0.13 | 0.15 | 0.16 | 0.17 | 0.19 | 0.20 | 0.22 | 0.23 | 0.25
Secondary [V] | 1.03 | 1.23 | 1.45 | 1.65 | 1.87 | 2.09 | 2.32 | 2.55 | 2.79 | 3.03 | 3.29 | 3.55 | 3.83 | 4.11 | 4.42 | 4.73
Turns ratio | 18.68 | 18.69 | 18.67 | 18.70 | 18.70 | 18.88 | 18.90 | 18.92 | 18.93 | 18.96 | 18.98 | 18.99 | 19.00 | 19.00 | 19.03 | 19.04
RLC ressonance (R in series):
Rs [mΩ] | C [µF] | F [kHz] | L [µH] | Winding | Lavg [µH] | Lratio | Turns ratio from Lratio
7.47 | 0.085 | 267 | 4.18 | Pri
7.47 | 0.88 | 90 | 3.55 | Pri | 3.75
7.47 | 5 | 37.88 | 3.53 | Pri | 3.54
465.69 | 5 | 1.953 | 1328.09 | Sec
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

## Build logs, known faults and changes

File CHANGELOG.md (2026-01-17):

# Changelog

## [Unreleased]

## [1.1.0] - 2026-01-17

## [1.1.0] - 2026-01-16

### Changed

Replaced UC2843A by UC3845 - output signal is active only once every two cycles, indicating the IC matches UCx845 functionality. 

### Added

Measurement data (waveforms, transformer characteristics). See "Supporting docs"

## [1.0.2] - 2026-01-16

### Changed

Trying to fix changelog. Release discarded.

## [1.0.1] - 2025-12-21

### Changed

Changelog updates only - issue with missing changelog on revision 1.0.0

## [1.0.0] - 2025-12-19

### First issue

Schematic capture complete, except for parts:

-   not populated (D2, C9);
-   with unreadable or absent markings (F1, D4, R9, TR1).

CI failed on release - do not use.

[Unreleased]: https://github.com/FLRHW/StepUp_module_12to450V/compare/1.1.0...HEAD

[1.1.0]: https://github.com/FLRHW/StepUp_module_12to450V/compare/1.1.0...1.1.0

[1.1.0]: https://github.com/FLRHW/StepUp_module_12to450V/compare/1.0.1...1.1.0

[1.0.1]: https://github.com/FLRHW/StepUp_module_12to450V/compare/3e65155bfaba51fb4ad2638bce463ab48d852d69...1.0.1

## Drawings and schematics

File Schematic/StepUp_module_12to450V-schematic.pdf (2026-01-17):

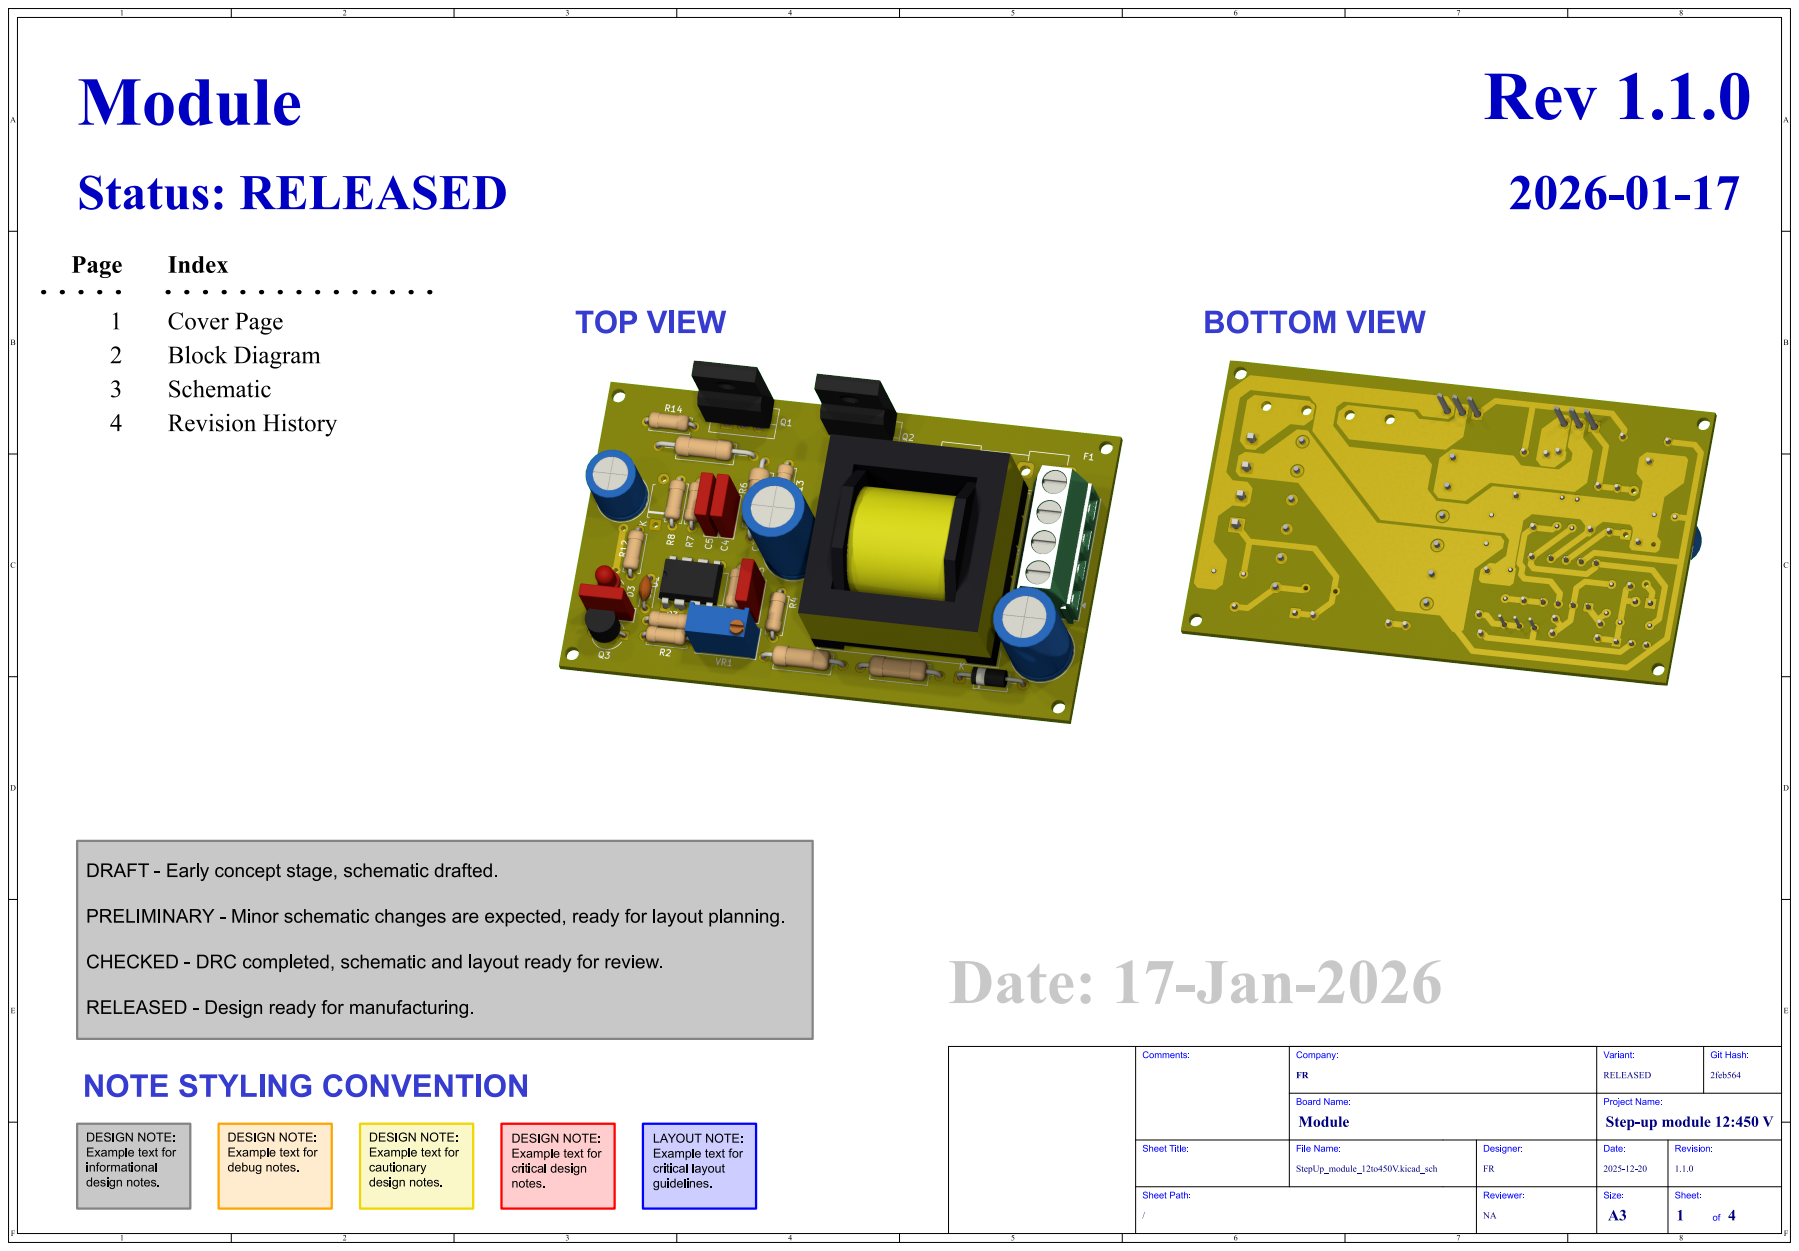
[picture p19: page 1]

DRAFT - Early concept stage, schematic drafted.

PRELIMINARY - Minor schematic changes are expected, ready for layout planning.

CHECKED - DRC completed, schematic and layout ready for review.

RELEASED - Design ready for manufacturing.
NOTE STYLING CONVENTION

Revision: 1.1.0 Date: Project Name: 2025-12-20 Reviewer: NADesigner:

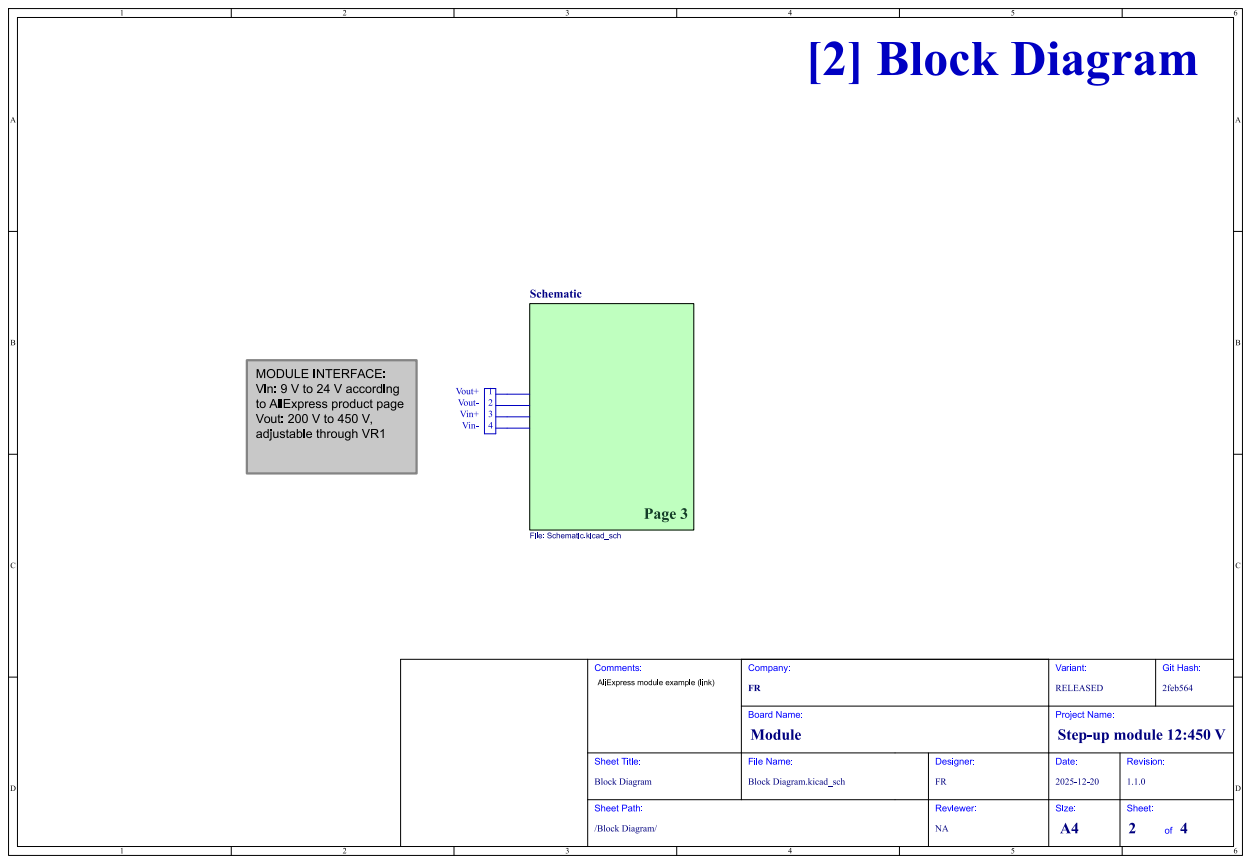
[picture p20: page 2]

File: Schematic.kicad_sch MODULE INTERFACE:
Vin: 9 V to 24 V according
to AliExpress product page
Vout: 200 V to 450 V,
adjustable through VR1

AliExpress module example (link) (https://www.aliexpress.com/item/1005006040711629.html)

/Block Diagram/ Sheet Path: Block Diagram

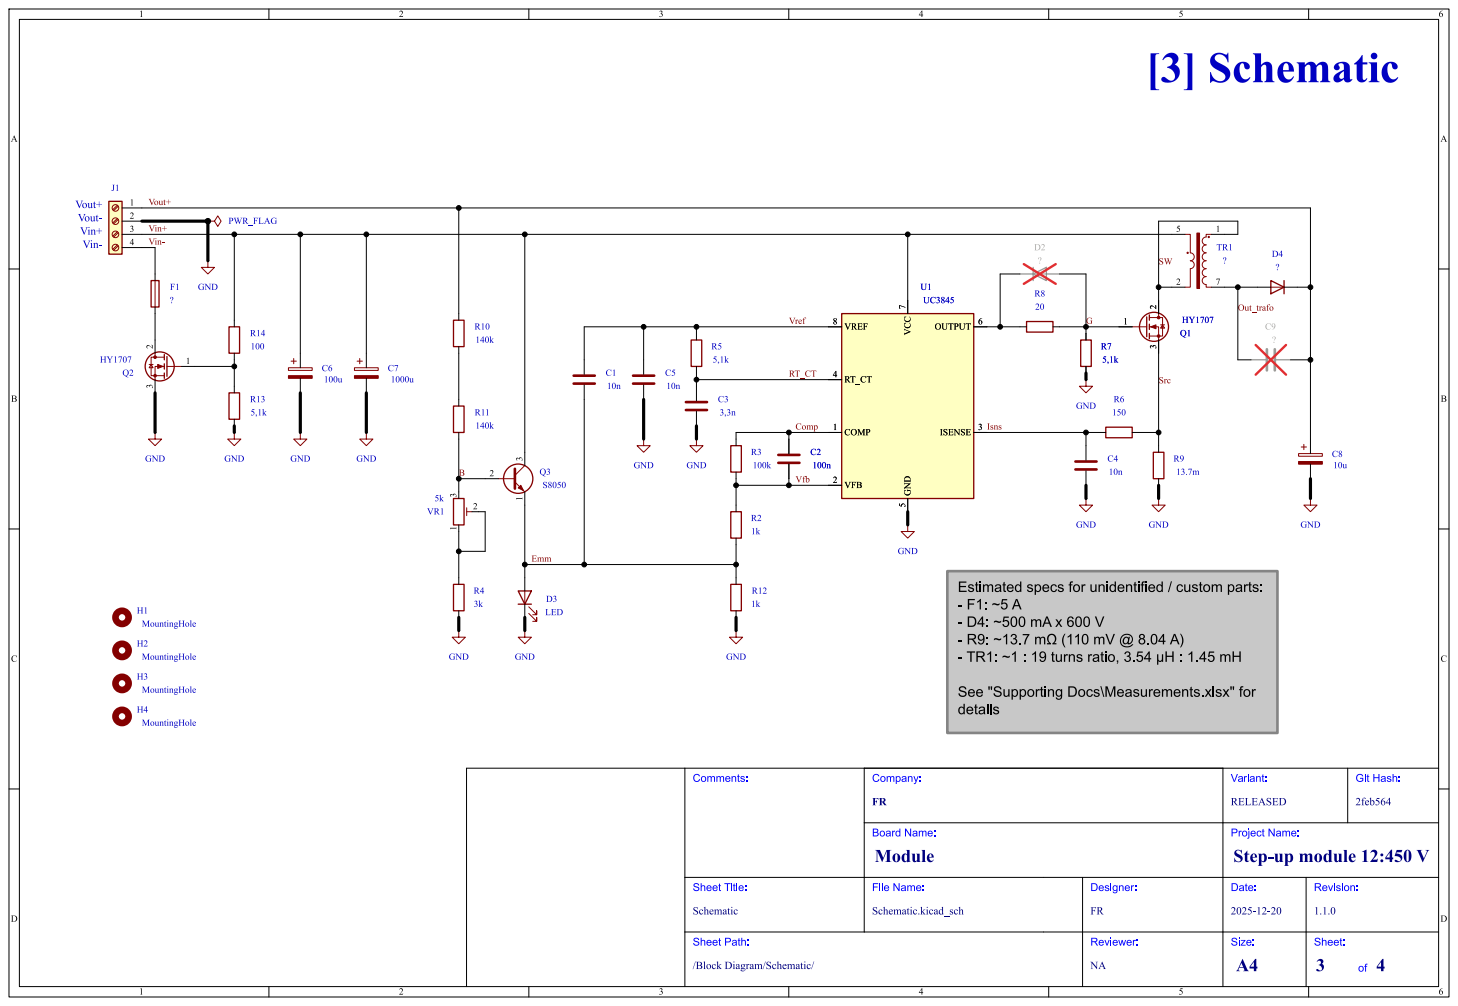
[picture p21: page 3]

- TR1: ~1 : 19 turns ratio, 3.54 þÿ¼H: 1.45 mH

See "Supporting Docs\Measurements.xlsx" for
details

Revision: 1.1.0 Date: Project Name: 2025-12-20 Reviewer: NADesigner:

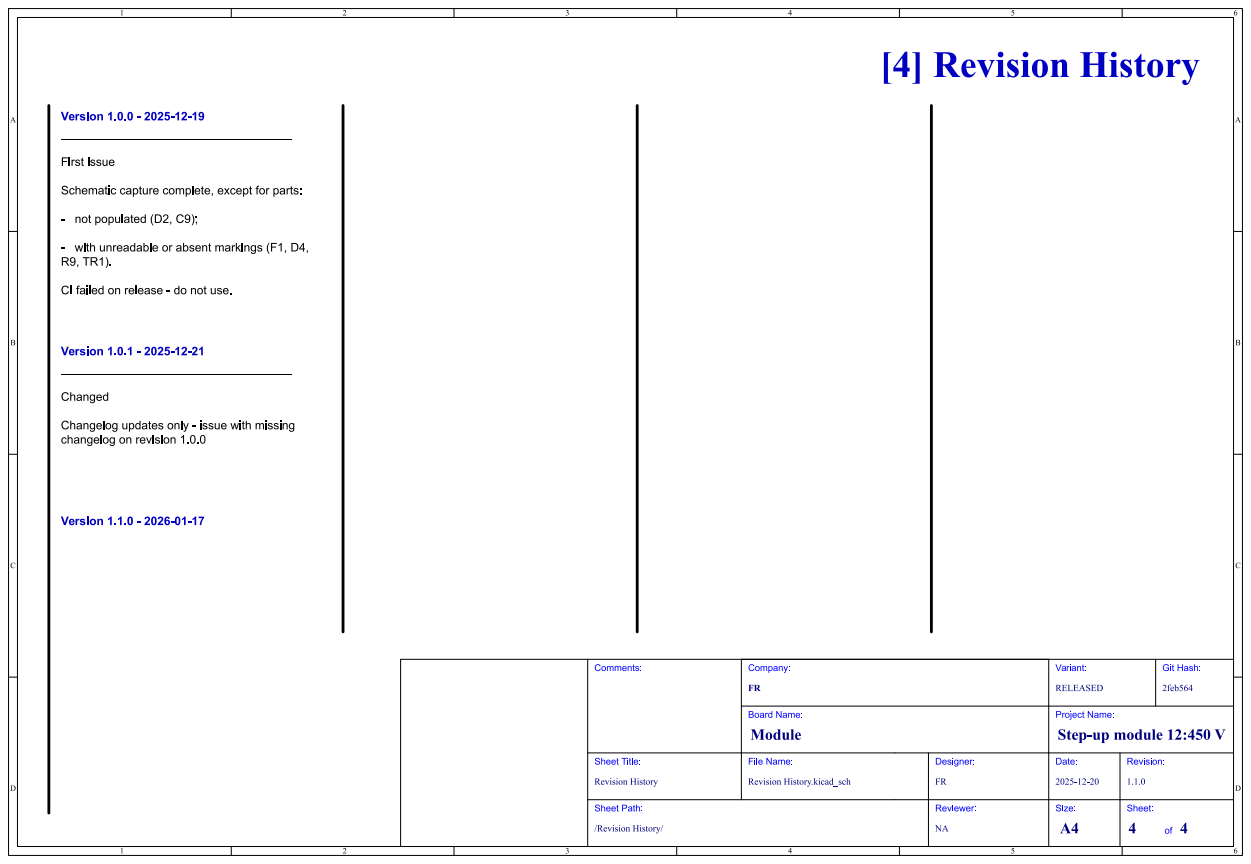
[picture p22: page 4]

Schematic capture complete, except for parts: - not populated (D2, C9); - with unreadable or absent markings (F1, D4,

CI failed on release - do not use. Version 1.1.0 - 2026-01-17

Changelog updates only - issue with missing
changelog on revision 1.0.0

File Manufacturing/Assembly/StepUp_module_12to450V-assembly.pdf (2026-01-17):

# Module Assembly Document

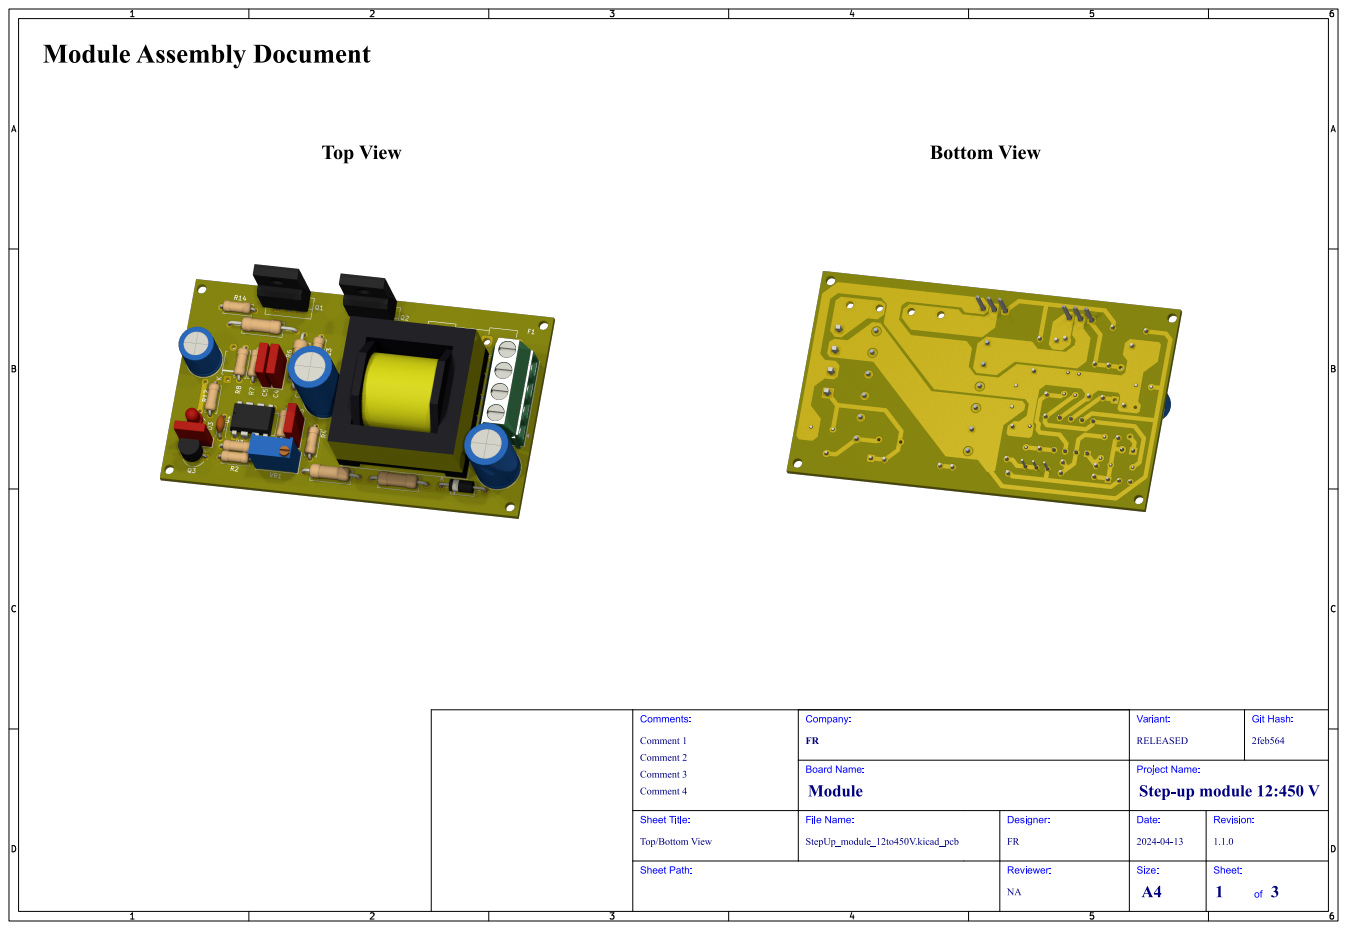
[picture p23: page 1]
Git; Hash:; 2feb564; Comment 4; Comment 3; Comment 2; Comment 1; Comments:; Sheet Path:; Sheet Title:; File Name:; Module; Step-up module 12:450 V; Company:; RELEASED; Variant:; Board Name:; StepUp_module_12to450V.kicad_pcb; Designer:; Reviewer:; Project Name:; Date:; Revision:; Size:; Sheet:

Top/Bottom View

# Top Assembly (Scale 1:1)

# Module Assembly Document

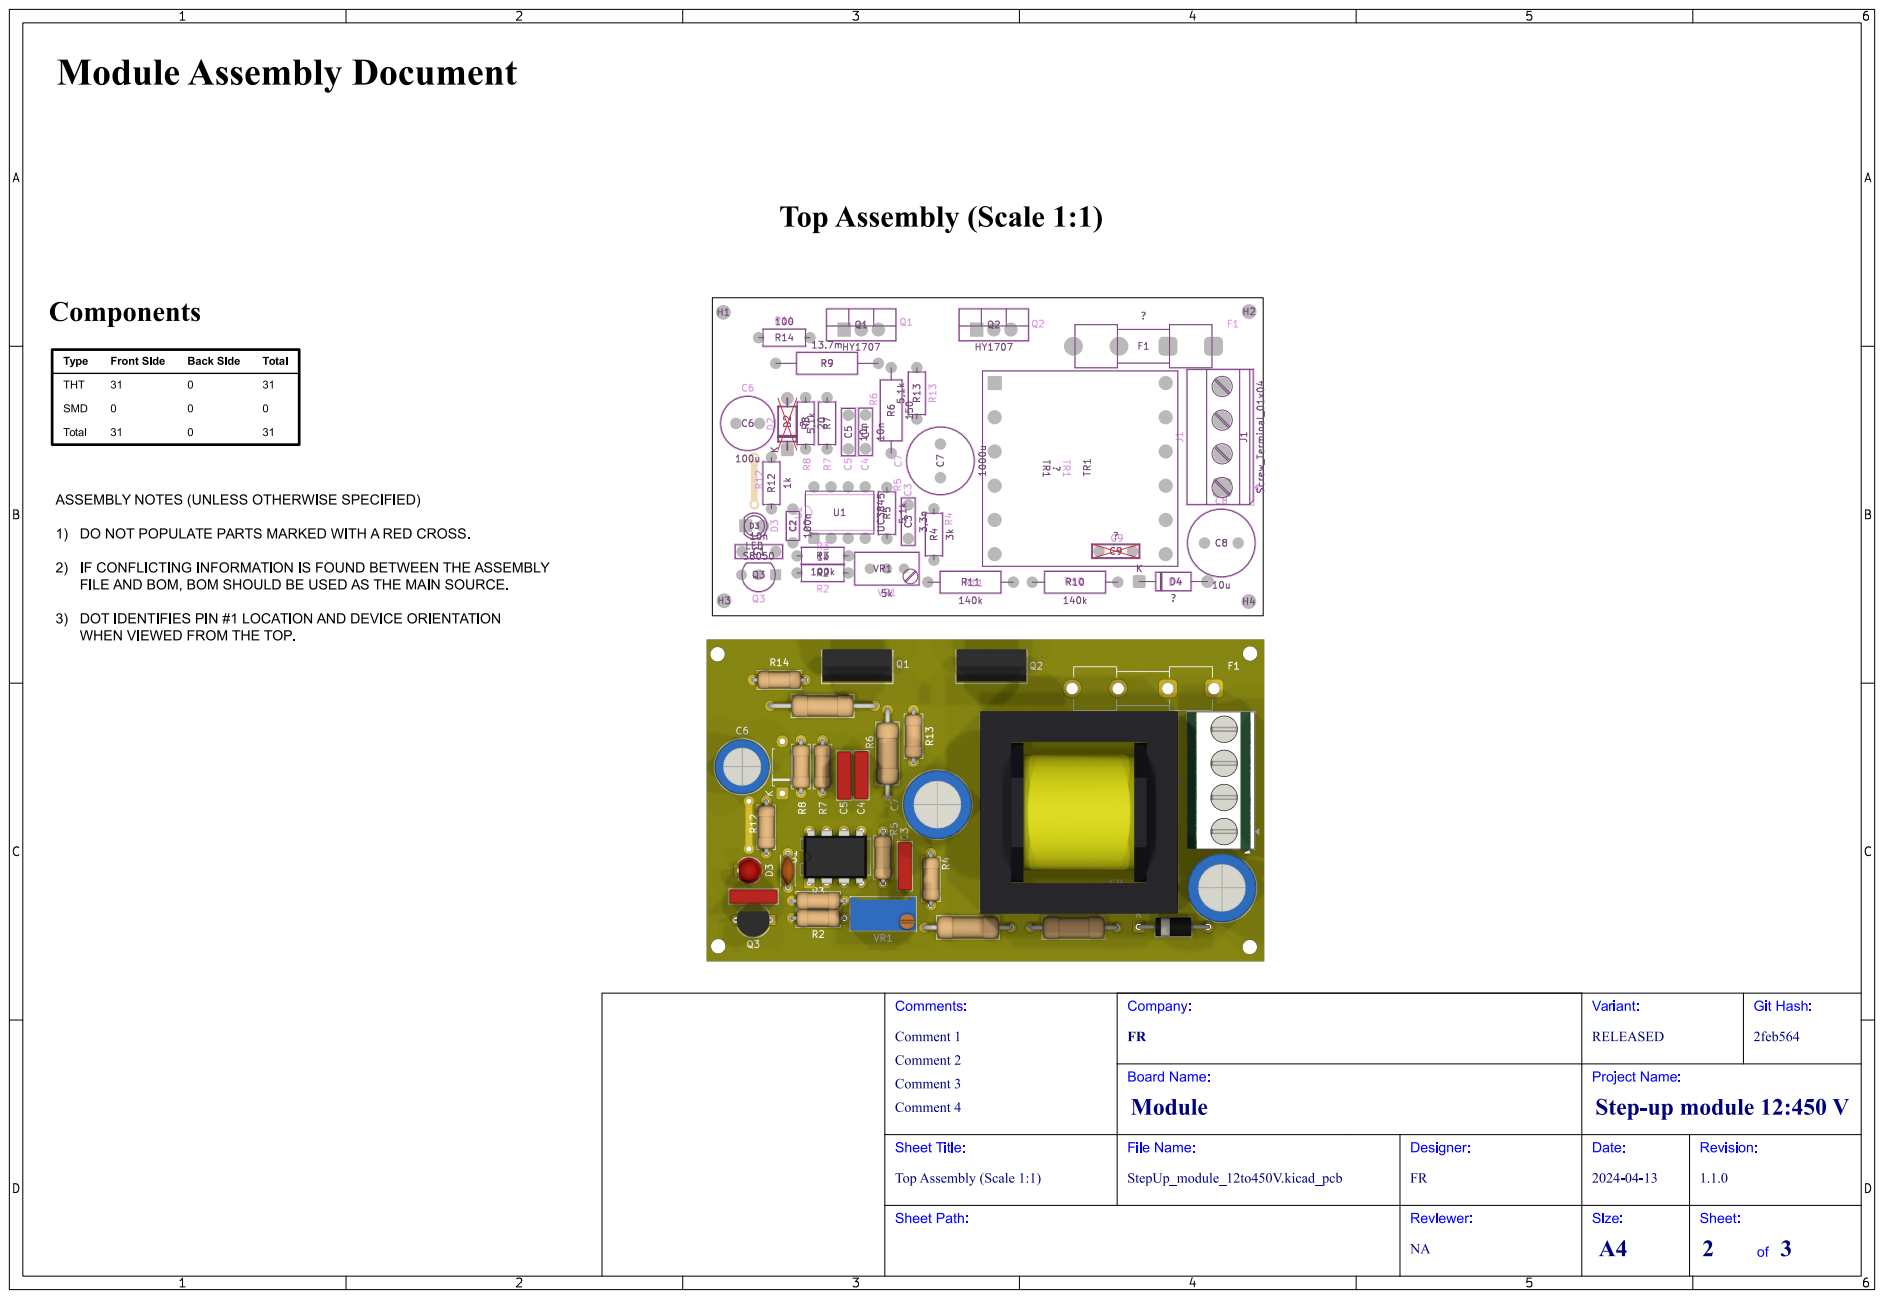
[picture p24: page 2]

# Bottom Assembly (Scale 1:1)

# Module Assembly Document

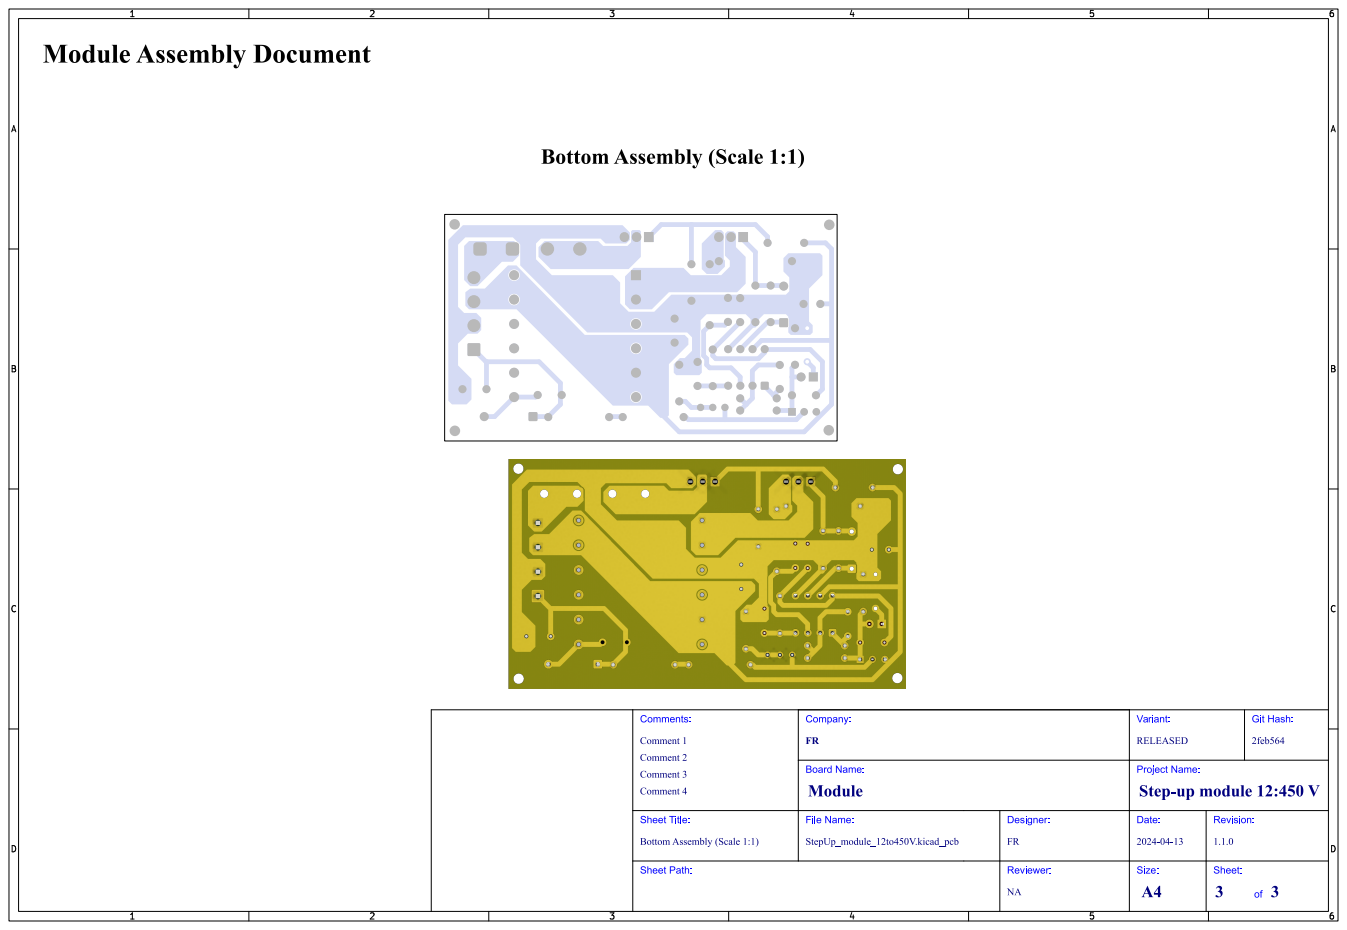
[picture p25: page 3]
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

Bottom Assembly (Scale 1:1)

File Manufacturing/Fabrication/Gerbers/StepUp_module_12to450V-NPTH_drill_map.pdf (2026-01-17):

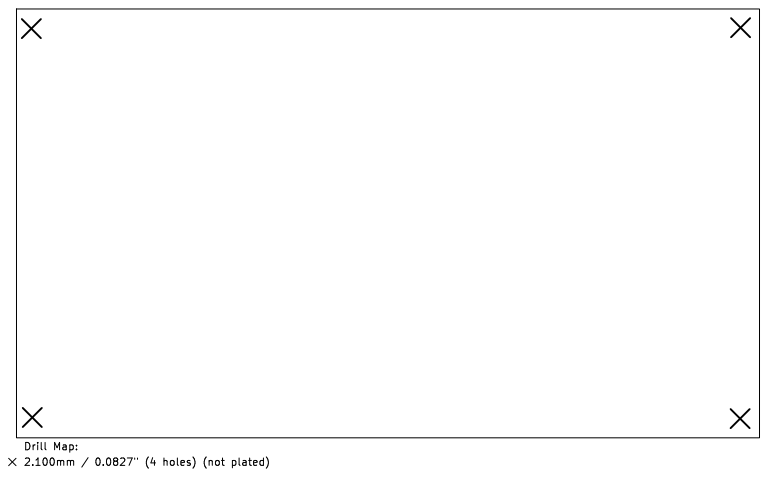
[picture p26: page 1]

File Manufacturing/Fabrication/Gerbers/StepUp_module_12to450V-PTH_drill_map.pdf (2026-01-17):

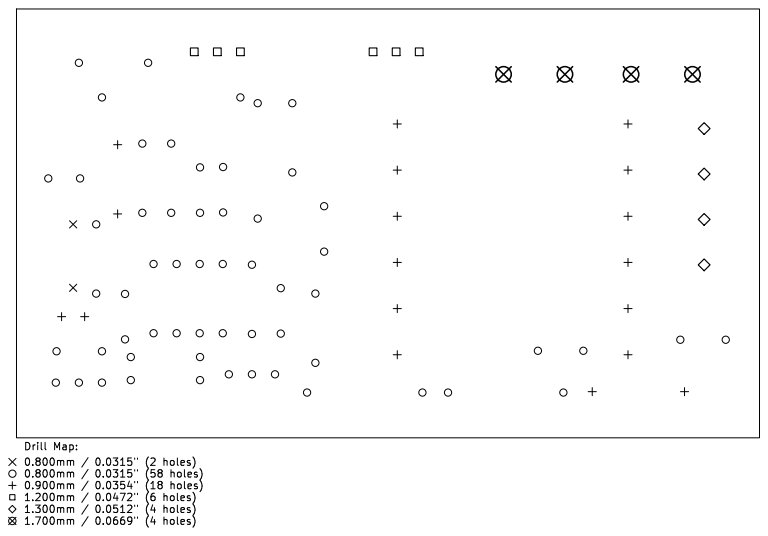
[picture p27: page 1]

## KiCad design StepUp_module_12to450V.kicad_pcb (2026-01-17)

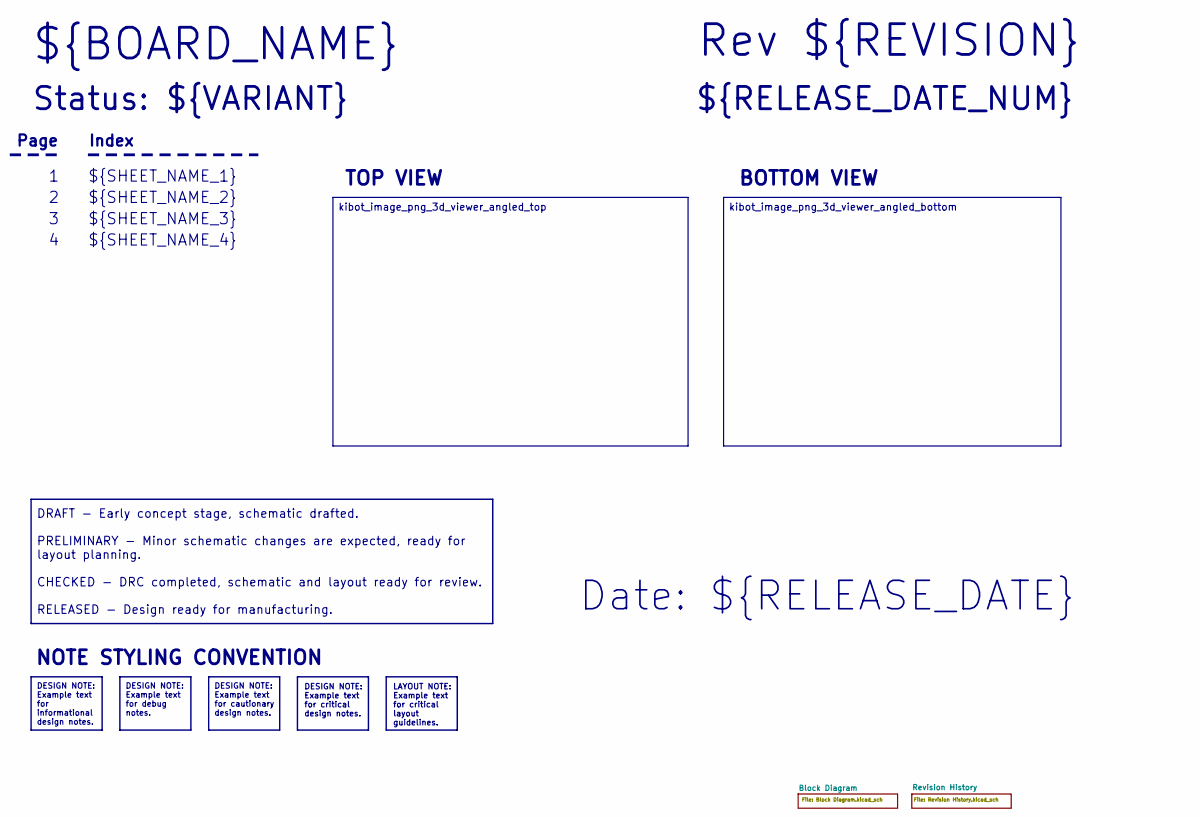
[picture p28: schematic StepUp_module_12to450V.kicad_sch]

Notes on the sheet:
Status: ${VARIANT}
${SHEET_NAME_2}
Page
${RELEASE_DATE_NUM}
Rev ${REVISION}
BOTTOM VIEW
Date: ${RELEASE_DATE}
${BOARD_NAME}
${SHEET_NAME_1}
${SHEET_NAME_3}
TOP VIEW
Index
${SHEET_NAME_4}
NOTE STYLING CONVENTION
DESIGN NOTE: Example text for cautionary design notes.
DESIGN NOTE: Example text for debug notes.
DESIGN NOTE: Example text for critical design notes.
LAYOUT NOTE: Example text for critical layout guidelines.
kibot_image_png_3d_viewer_angled_bottom
DESIGN NOTE: Example text for informational design notes.
kibot_image_png_3d_viewer_angled_top
DRAFT - Early concept stage, schematic drafted. PRELIMINARY - Minor schematic changes are expected, ready for layout planning. CHECKED - DRC completed, schematic and layout ready for review. RELEASED - Design ready for manufacturing.

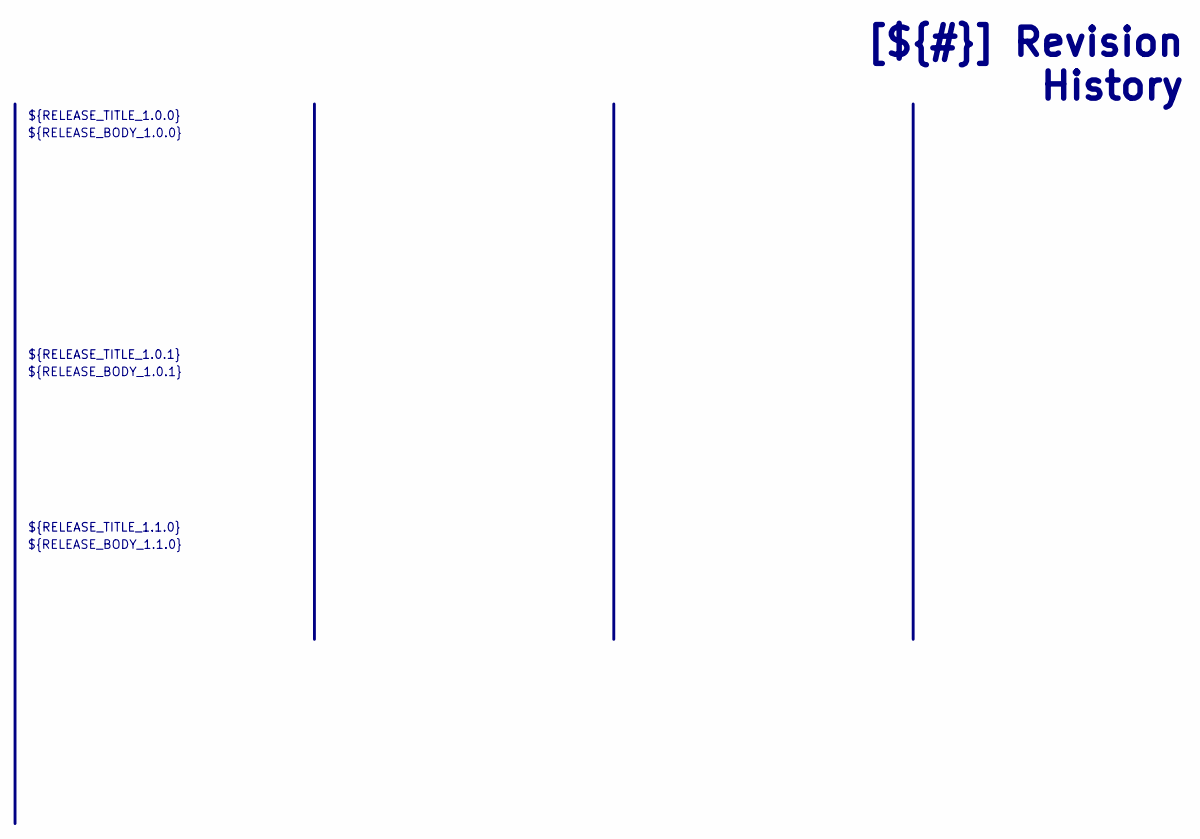
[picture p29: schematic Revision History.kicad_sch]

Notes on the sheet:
[${#}] ${TITLE}
${RELEASE_BODY_1.0.0}
${RELEASE_TITLE_1.1.0}
${RELEASE_BODY_1.1.0}
${RELEASE_BODY_1.0.1}
${RELEASE_TITLE_1.0.0}
${RELEASE_TITLE_1.0.1}

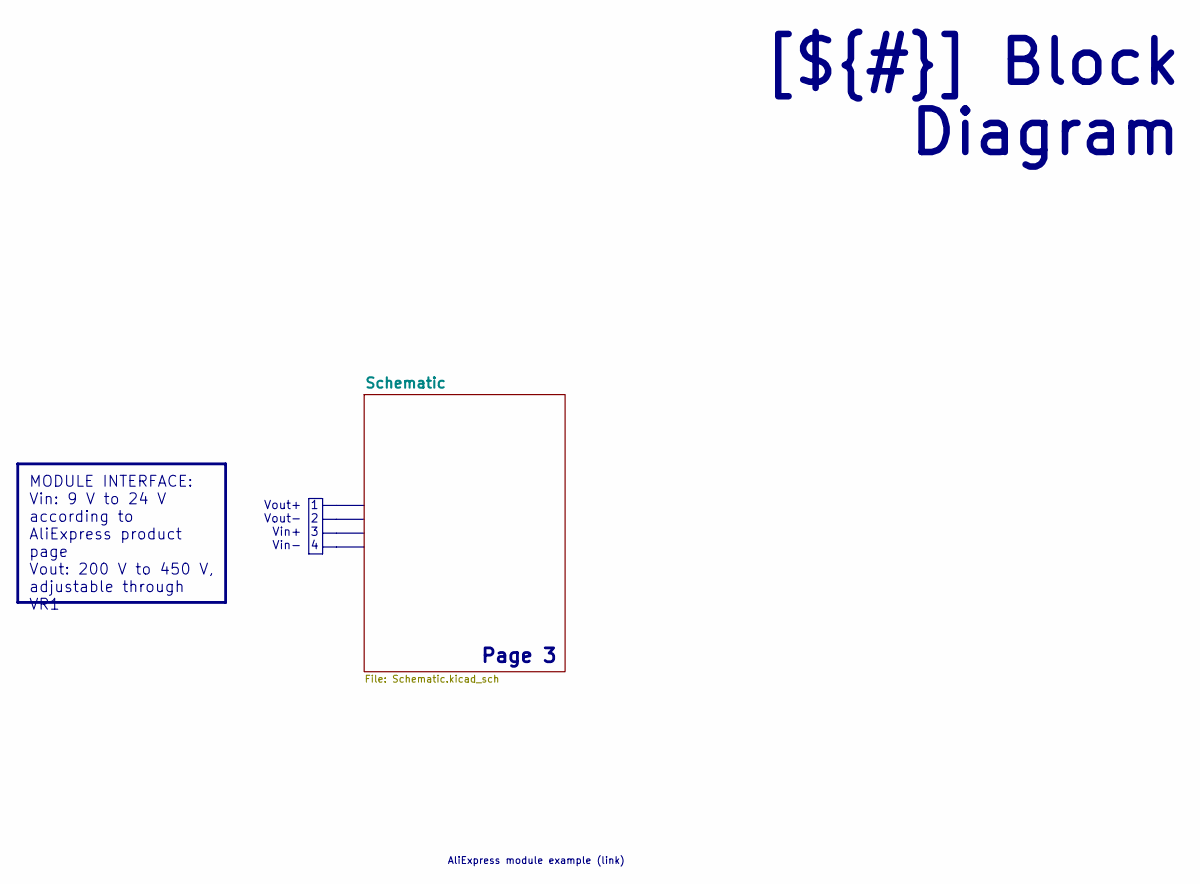
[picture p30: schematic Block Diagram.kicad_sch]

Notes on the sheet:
Page 3
1 2 3 4
Vout+ Vout- Vin+ Vin-
AliExpress module example (link)
MODULE INTERFACE: Vin: 9 V to 24 V according to AliExpress product page Vout: 200 V to 450 V, adjustable through VR1
[${#}] ${TITLE}

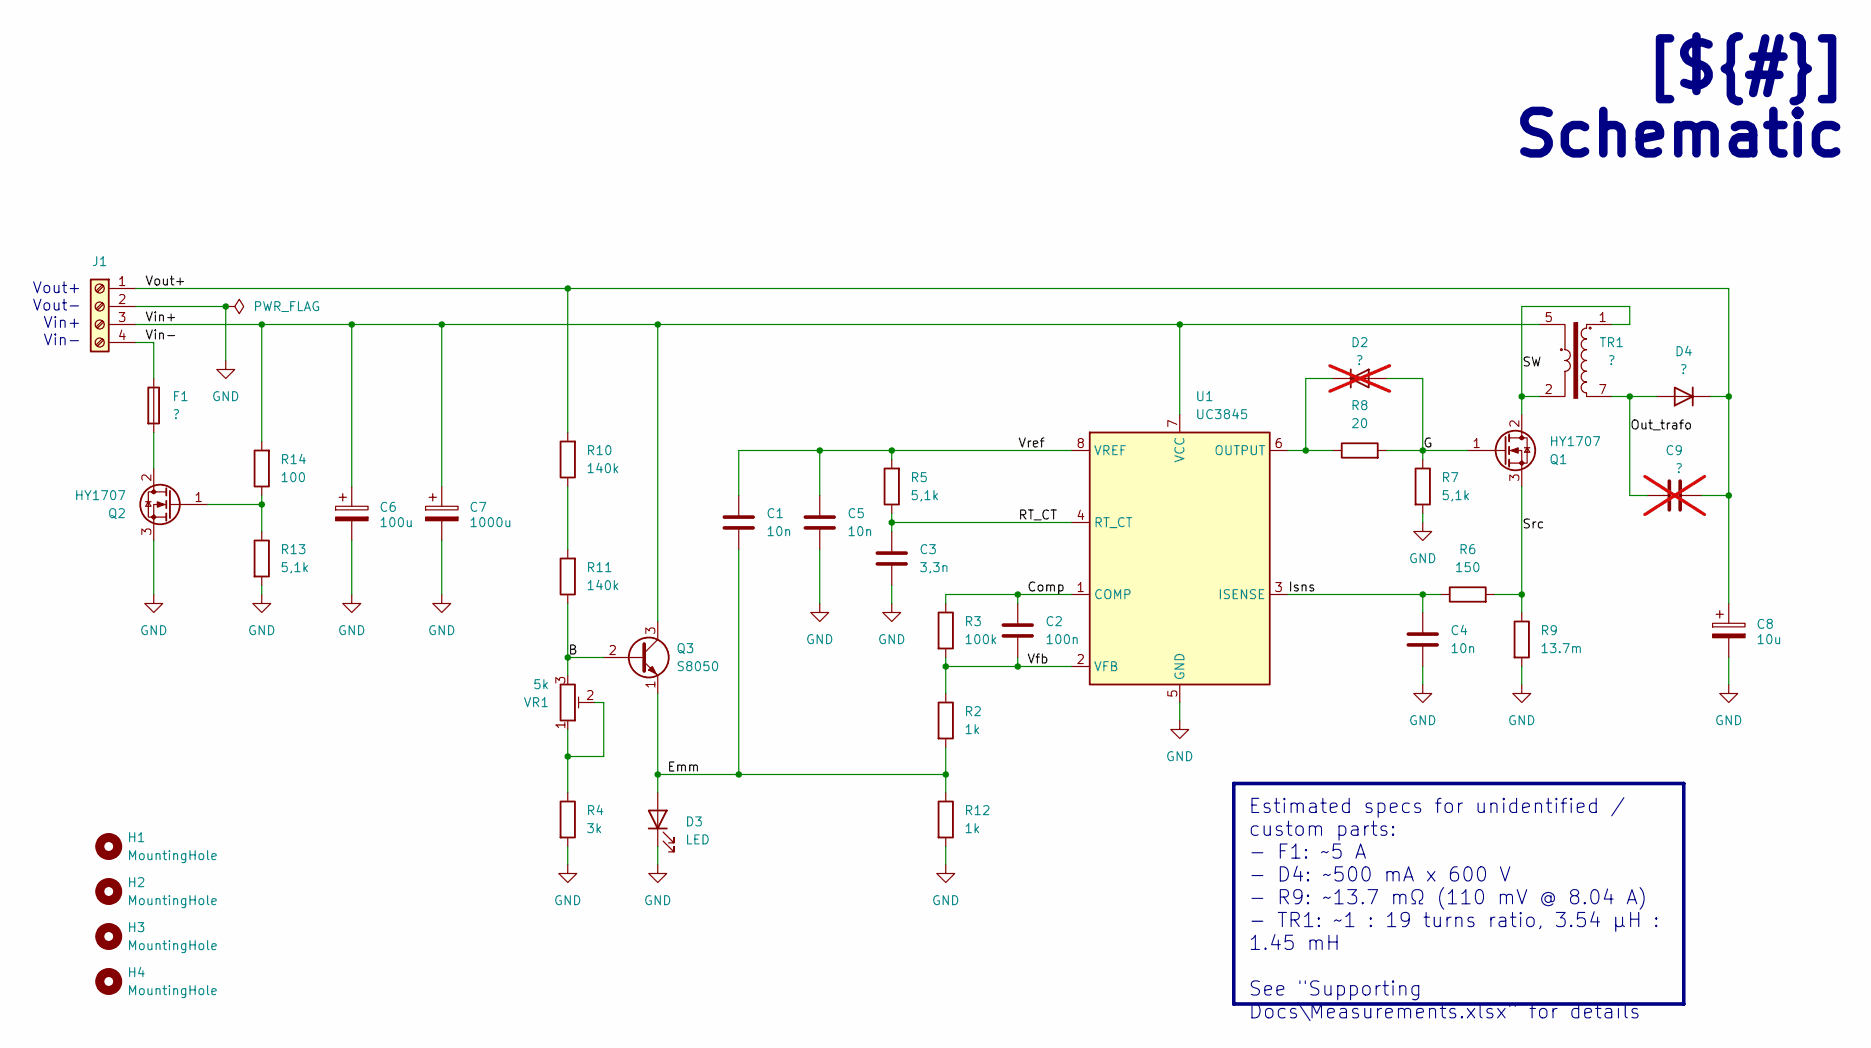
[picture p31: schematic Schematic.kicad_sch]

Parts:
C1, C4, C5: 10n; C_Rect_L7.0mm_W2.0mm_P5.00mm
C2: 100n; C_Disc_D4.3mm_W1.9mm_P5.00mm
C3: 3,3n; C_Rect_L7.0mm_W2.0mm_P5.00mm
C6: 100u; C_Radial_D8.0mm_H11.5mm_P3.50mm
C7: 1000u; C_Radial_D10.0mm_H20.0mm_P5.00mm
C8: 10u; C_Radial_D10.0mm_H16.0mm_P5.00mm
C9: ?; C_Rect_L7.0mm_W2.0mm_P5.00mm; not fitted
D2: ?; D_A-405_P7.62mm_Horizontal; not fitted
D3: LED; LED_D3.0mm
D4: ?; D_A-405_P10.16mm_Horizontal
F1: ?; Fuseholder_Clip-5x20mm_Eaton_1A5601-01_Inline_P20.80x6.76mm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
H1, H2, H3, H4: MountingHole; MountingHole_2.1mm
J1: Screw_Terminal_01x04; TerminalBlock_Phoenix_MKDS-1,5-4_1x04_P5.00mm_Horizontal
Q1, Q2: HY1707; TO-220F-3_Vertical
Q3: S8050; TO-92_Inline_Wide
R2, R12: 1k; R_Axial_DIN0207_L6.3mm_D2.5mm_P7.62mm_Horizontal
R3: 100k; R_Axial_DIN0207_L6.3mm_D2.5mm_P7.62mm_Horizontal
R4: 3k; R_Axial_DIN0207_L6.3mm_D2.5mm_P7.62mm_Horizontal
R5, R7, R13: 5,1k; R_Axial_DIN0207_L6.3mm_D2.5mm_P7.62mm_Horizontal
R6: 150; R_Axial_DIN0309_L9.0mm_D3.2mm_P12.70mm_Horizontal
R8: 20; R_Axial_DIN0207_L6.3mm_D2.5mm_P7.62mm_Horizontal
R9: 13.7m; R_Axial_DIN0309_L9.0mm_D3.2mm_P15.24mm_Horizontal
R10, R11: 140k; R_Axial_DIN0309_L9.0mm_D3.2mm_P12.70mm_Horizontal
R14: 100; R_Axial_DIN0207_L6.3mm_D2.5mm_P7.62mm_Horizontal
TR1: ?; Tr12to450V_Alixp
U1: UC3845; DIP-8_W7.62mm
VR1: 5k; Potentiometer_Bourns_3296W_Vertical

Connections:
/Block Diagram/Schematic/B: Q3.2 (B), R11.1, VR1.3
/Block Diagram/Schematic/Comp: C2.1, R3.1, U1.1 (COMP)
/Block Diagram/Schematic/Emm: C1.1, D3.2 (A), Q3.1 (E), R2.2, R12.1
/Block Diagram/Schematic/G: D2.2 (A), Q1.1 (G), R7.1, R8.2
/Block Diagram/Schematic/Isns: C4.1, R6.1, U1.3 (ISENSE)
/Block Diagram/Schematic/Out_trafo: C9.1, D4.2 (A), TR1.7
/Block Diagram/Schematic/RT_CT: C3.1, R5.1, U1.4 (RT_CT)
/Block Diagram/Schematic/SW: Q1.2 (D), TR1.1, TR1.2
/Block Diagram/Schematic/Src: Q1.3 (S), R6.2, R9.1
/Block Diagram/Schematic/Vfb: C2.2, R2.1, R3.2, U1.2 (VFB)
/Block Diagram/Schematic/Vin+: C6.1, C7.1, J1.3, Q3.3 (C), R14.2, TR1.5, U1.7 (VCC)
/Block Diagram/Schematic/Vin-: F1.1, J1.4
/Block Diagram/Schematic/Vout+: C8.1, C9.2, D4.1 (K), J1.1, R10.2
/Block Diagram/Schematic/Vref: C1.2, C5.1, R5.2, U1.8 (VREF)
GND: C3.2, C4.2, C5.2, C6.2, C7.2, C8.2, D3.1 (K), J1.2, Q2.3 (S), R4.2, R7.2, R9.2, R12.2, R13.2, U1.5 (GND)
unnamed: D2.1 (K), R8.1, U1.6 (OUTPUT)
unnamed: F1.2, Q2.2 (D)
unnamed: Q2.1 (G), R13.1, R14.1
unnamed: R4.1, VR1.1, VR1.2
unnamed: R10.1, R11.2

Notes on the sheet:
Vout+ Vout- Vin+ Vin-
[${#}] ${TITLE}
Estimated specs for unidentified / custom parts: - F1: ~5 A - D4: ~500 mA x 600 V - R9: ~13.7 mΩ (110 mV @ 8.04 A) - TR1: ~1 : 19 turns ratio, 3.54 μH : 1.45 mH See "Supporting Docs\Measurements.xlsx" for details

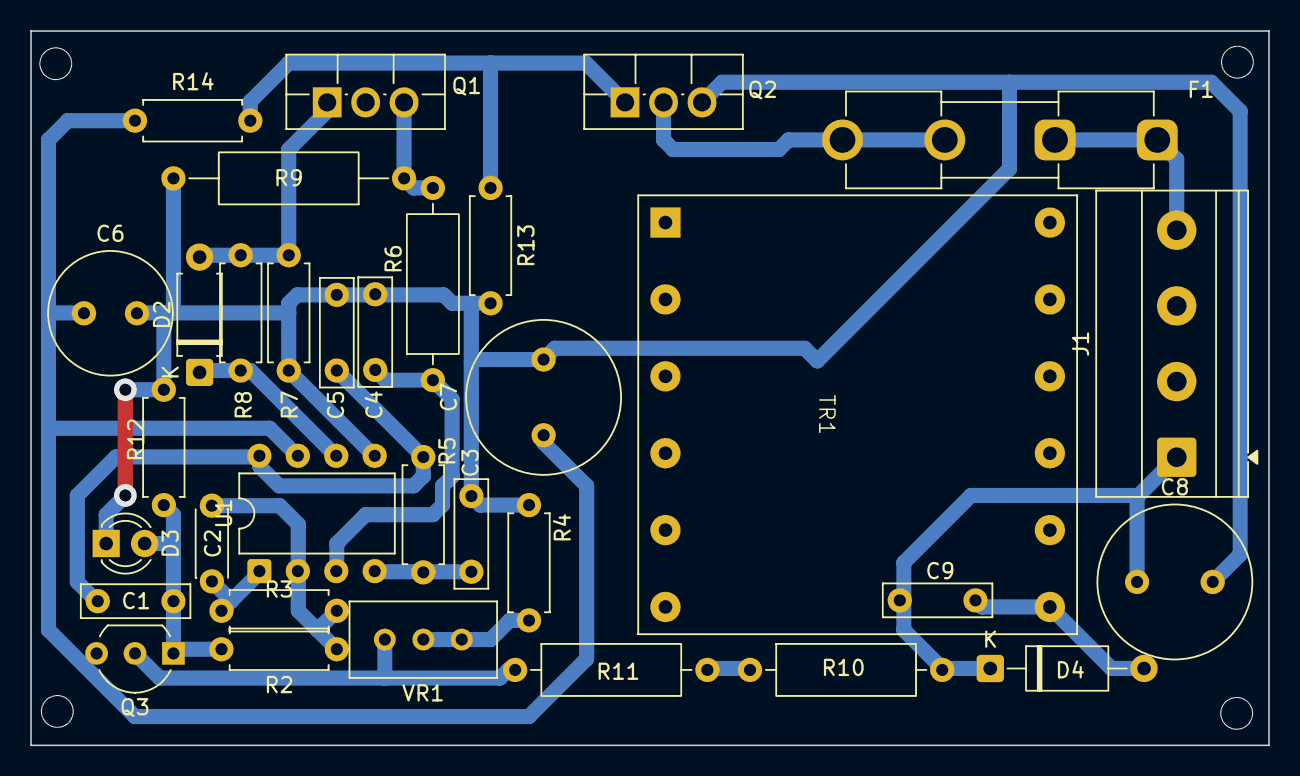
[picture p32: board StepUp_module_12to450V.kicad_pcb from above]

Board: 2 copper layers, 81.8 x 47.2 mm, 37 parts (0 on the bottom side), 20 nets.

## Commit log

2025-12-12 Initial commit. Schematic capture and PCB layout replication nearly complete
    [Block Diagram.kicad_sch, Power - Sequencing.kicad_sch, Project Architecture.kicad_sch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]
2025-12-12 Update Outputs
    [StepUp_module_12to450V-bom.csv]
2025-12-13 updated gitignore
    [StepUp_module_12to450V.kicad_sch]
2025-12-13 Refreshed trafo symbol and footprint
    [StepUp_module_12to450V.kicad_sch]
2025-12-13 Updated readme template and status notes
    [Trafo_12to450V_module.step]
2025-12-13 Updated readme template, status comments and gitatributes
    [StepUp_module_12to450V.kicad_sch]
2025-12-13 Removed lib clone
    [Trafo_12to450V_module.step]
2025-12-14 Testing new path for custom 3D model
    [Project Architecture.kicad_sch, StepUp_module_12to450V.kicad_sch]
2025-12-14 New 3D path for trafo
    [Block Diagram.kicad_sch, Project Architecture.kicad_sch, Section A - Title A.kicad_sch]
2025-12-14 Trying to solve TOC issues
    [Project Architecture.kicad_sch, Schematic.kicad_sch, Section B - TItle B.kicad_sch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]
2025-12-14 testing lib issue
    [Block Diagram.kicad_sch, Revision History.kicad_sch, Schematic.kicad_sch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]
2025-12-14 Updated some footpints
    [Power - Sequencing.kicad_sch, Project Architecture.kicad_sch, Schematic.kicad_sch]
2025-12-14 Updated terminal block
    [Schematic.kicad_sch]
2025-12-15 DRC completed, changed status to checked
    [StepUp_module_12to450V.kicad_sch]
2025-12-16 Rev history text added
    [StepUp_module_12to450V-L6 (Sig, PWR).gbr]
2025-12-17 Revert to DRC completed
    [StepUp_module_12to450V-B_Mask.gbr, StepUp_module_12to450V-B_Silkscreen.gbr, StepUp_module_12to450V-CPL.csv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]
2025-12-19 Fixed PCB polygons
    [StepUp_module_12to450V.kicad_sch]
2025-12-19 Revert "Fixed PCB polygons"
    This reverts commit dcaf8486db0413924995f75ee6d491de60b936f0.
    [StepUp_module_12to450V.kicad_sch]
2025-12-19 Revert "Update Outputs"
    This reverts commit f9744f7c91168a221b7741dfeae28b67c08d2c58.
    [StepUp_module_12to450V.step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]
2025-12-19 Preping release 1.0.0
    [StepUp_module_12to450V.kicad_sch]
2025-12-19 Solving rev hist
    [StepUp_module_12to450V.kicad_sch]
2025-12-19 Solving rev hist again
    [StepUp_module_12to450V.kicad_sch]
2025-12-20 Rev hist update
    [StepUp_module_12to450V.kicad_sch]
2025-12-20 Added notes for unidentified parts
    [Schematic.kicad_sch]
2025-12-20 General notes added
    [Block Diagram.kicad_sch, Revision History.kicad_sch, Schematic.kicad_sch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]
2025-12-20 Update Outputs (release)
    [StepUp_module_12to450V-B_Mask.gbr, StepUp_module_12to450V-B_Paste.gbr, StepUp_module_12to450V-B_Silkscreen.gbr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]
2025-12-21 Fixed changelog
    [Revision History.kicad_sch]
2025-12-21 Forcing CI
    [Block Diagram.kicad_sch]
2026-01-16 Updated switcher IC
    [Measurements.xlsx, Revision History.kicad_sch, Schematic.kicad_sch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]
2026-01-16 Fixed ci and kibot_main, fixed DRC issue
    [StepUp_module_12to450V.kicad_pcb]
2026-01-16 Reverted changelog file to debug issue
    [Schematic.kicad_sch]
2026-01-16 Fixed pre_set_text and restored changelog
    [Schematic.kicad_sch]
2026-01-16 fixed another issue in pre_set_text
    [Schematic.kicad_sch]
2026-01-16 resolving corrupted project
    [Revision History.kicad_sch]
2026-01-16 removed unresolved text boxes
    [Revision History.kicad_sch]
2026-01-17 Test 1
    [Revision History.kicad_sch]
2026-01-17 Ready to release
    [StepUp_module_12to450V.kicad_sch]
